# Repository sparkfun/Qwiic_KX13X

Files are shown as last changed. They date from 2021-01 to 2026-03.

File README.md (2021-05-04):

SparkFun Triple-Axis Accelerometer Breakout - KX13x (Qwiic)
========================================

<table class="table table-hover table-striped table-bordered">
    <tr align="center">
      <td></td>
      <td></td>
    </tr>
    <tr align="center">
      <td><a href="https://www.sparkfun.com/products/17871">SparkFun Triple-Axis Accelerometer Breakout - KX132 (Qwiic)</a></td>
      <td><a href="https://www.sparkfun.com/products/17589">SparkFun Triple-Axis Accelerometer Breakout - KX134 (Qwiic)</a></td>
    </tr>
</table>

The Triple-Axis Accelerometer Breakout - KX132 & KX134 (Qwiic) are simple Qwiic breakouts for a pair of high-speed digital accelerometers from Kionix. Both accelerometers have four user-selectable ranges (KX132: &plusmn;2/4/8/16g & KX134: &plusmn;8/16/32/64g) with sensitivity as high as 17367 counts/g @&plusmn;2g (highest KX134 setting is 4424 counts/g @&plusmn;8g) and Output Data Rate up to 25600Hz. The KX134 and KX132 also feature a host of accelerometer features including Freefall detection, Directional Tap<sup>&trade;</sup> and Double-Tap<sup>&trade;</sup> detection, tilt orientation detection and more.

Repository Contents
-------------------

* **/Documentation** - Data sheets, additional product information
* **/Hardware** - Eagle design files (.brd, .sch)
* **/Production** - Production panel files (.brd)

Documentation
--------------
* **[SparkFun Qwiic KX13x Library](https://github.com/sparkfun/SparkFun_KX13X_Arduino_Library)** - Arduino library for the Triple-Axis Accelerometer Breakout - KX13x (Qwiic).
* **[SparkFun Qwiic KX13x_Py](https://github.com/sparkfun/Qwiic_KX13X_Py)** - Python module for the Triple-Axis Accelerometer Breakout - KX13x (Qwiic).
* **[Hookup Guide](https://learn.sparkfun.com/tutorials/triple-axis-accelerometer-breakout---kx13x-qwiic-hookup-guide-)** - Basic hookup guide for the Triple-Axis Accelerometer Breakout - KX13x (Qwiic).

Product Versions
----------------
* [SEN-17871](https://www.sparkfun.com/products/17871) - KX132 Version initial release (v10).
* [SEN-17589](https://www.sparkfun.com/products/17589) - KX134 Version initial release (v10).

License Information
-------------------

This product is _**open source**_! 

Please review the LICENSE.md file for license information. 

If you have any questions or concerns on licensing, please contact technical support on our [SparkFun forums](https://forum.sparkfun.com/viewforum.php?f=152).

Distributed as-is; no warranty is given.

- Your friends at SparkFun.

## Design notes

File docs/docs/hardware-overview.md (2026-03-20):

# Hardware Overview

## KX132 & KX134 3-Axis Accelerometers

First up let's examine the two accelerometers on the boards, highlight their specifications and how they differ. The KX134-1211 and KX132-1211 offer the following features:

* Four User-Selectable Measurement Ranges
  * KX134: ±8 / 16 / 32 / 64g
  * KX132: ±2 / 4 / 8 / 16g
* User-configurable 3-stage Advanced Data Path (ADP) with low-pass filter, low-pass/high-pass filter and RMS calculation engine
* User-selectable Low Power or High-Performance Modes
* Configurable Output Data Rate (ODR) up to 25,600Hz
* High resolution Wake-Up / Back-to-Sleep functions with configurable thresholds (as low as 15.6mg on the KX134 & 39mg on the KX132)
* Free fall detection
* Directional-Tap™/Double-Tap™
* Device Orientation algorithms
* Embedded 512-byte FIFO buffer (continues to record while being read)
* Digital I²C up to 3.4MHz and Digital SPI up to 10MHz

<figure align="center">
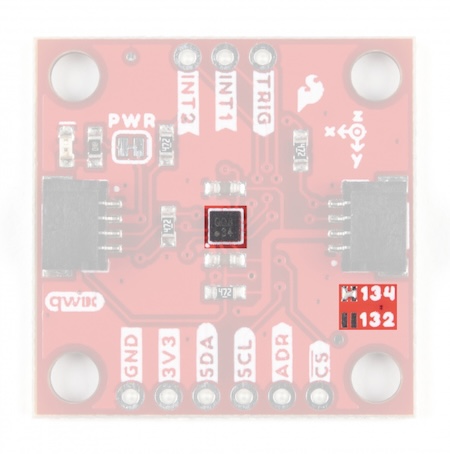
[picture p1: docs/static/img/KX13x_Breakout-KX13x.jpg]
Photo highlighting KX134 IC and KX13x version jumpers

<figcaption>KX134 IC and KX13x version jumpers</figcaption>
</figure>

:::note
As these boards both share the same PCB design, a closed solder jumper located below the "right" side Qwiic connector indicates the version (KX132 or KX134). The photo above highlights this solder jumper. This solder jumper does *not* effect the functionality of the board and is purely for identification purposes.
:::

The KX13x also includes an integrated voltage regulator to maintain consistent performance across its entire supply voltage range (**1.7** to **3.6V**). The table below outlines some of the electrical and functional characteristics of the KX134-1211 and KX132-1211 from the sensors' datasheets. All values in the table apply to both accelerometers unless specifically noted in the table or notes below it. Refer to the accelerometers' datasheets for a full overview: [KX132-1211](https://cdn.sparkfun.com/assets/d/a/1/c/0/KX132-1211-Specifications-Rev-1.0.pdf) & [KX134-1211](https://cdn.sparkfun.com/assets/6/a/2/c/b/KX134-1211-Specifications-Rev-1.0.pdf).

| Parameter | | Units | Min | Typical | Max |
| --- | --- | --- | --- | --- | --- |
| Supply Voltage (VDD) | | V | 1.7 | 2.5 (3.3 for use with Qwiic) | 3.6 |
| Current Consumption (Accelerometer Only) | High Performance w/Wake-up Detection (ODR=800Hz) | µA | | 148 | |
| | Low Power w/Wake-up Detection (ODR=0.781Hz, 2 samples averaged) | µA | | 0.53 | |
| | Standby | µA | | 0.50 | |
| Operating Temperature Range | | °C | -40 | - | 105 |
| Output Data Rate | | Hz | 0.781 | 50 | 25600 |
| Sensitivity (16 bit) | ±2g <sup>[1]</sup> | counts/g | 14501 | 16384 | 17367 |
| | ±4g <sup>[1]</sup> | counts/g | 7700 | 8192 | 8684 |
| | ±8g | counts/g | 3768 | 4096 | 4424 |
| | ±16g | counts/g | 1884 | 2048 | 2212 |
| | ±32g <sup>[2]</sup> | counts/g | 942 | 1024 | 1106 |
| | ±64g <sup>[2]</sup> | counts/g | 471 | 512 | 553 |
| Noise <sup>[3]</sup> | RMS | mg | | KX134: 1.9 / KX132: 0.7 | |
| | Density | µg/√Hz | | KX134: 300 / KX132: 150 | |
| I²C Address | | | | 0x1E (0x1F alternate) | |

> **[1]** Reminder: ±2/4g ranges are only available on the KX132.  
> **[2]** Reminder: ±32/64g ranges are only available on the KX134.  
> **[3]** Acceleration data noise varies depending on ODR, power mode & Average Filter Control settings. Noise measuring settings: High-Performance Mode (RES=1), ODR=50Hz, IIR Filter Enabled and IIR filter corner frequency set to ODR/2. Refer to Table 1 in the sensors' Datasheets as well as the Technical Reference Manuals for more information.

---

## Pinout

The KX13x Breakouts' I²C and SPI interface share the same pins so users must select the interface mode by altering the state of the ADR/SDO pin. The ADR jumper sets the state of the ADR/SDO pin (more on that in the Solder Jumpers section). Both breakouts operate in I²C mode by default. We've labeled these shared pins so I²C labels are visible from the front and SPI labels are visible when viewed from the back.

<figure alight="center">
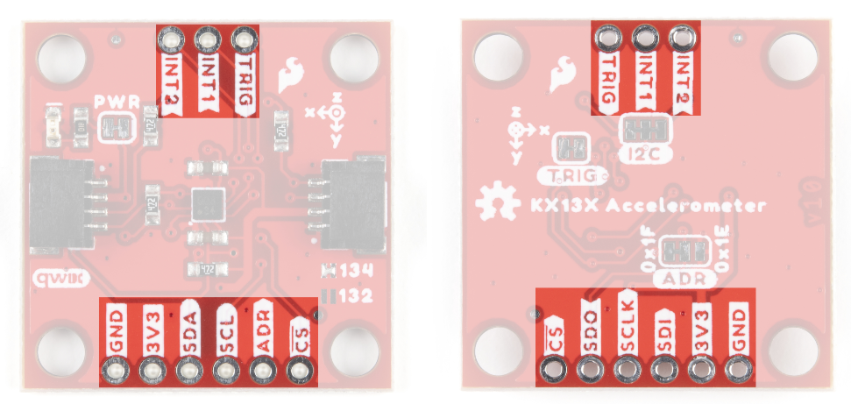
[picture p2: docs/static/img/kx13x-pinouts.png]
Photo highlighting the pinouts of the KX13x boards

<figcaption>The pinouts of the KX13x boards</figcaption>
</figure>

### Qwiic and I²C Interface

As you would expect on a Qwiic breakout, the boards break out the KX134's I²C pins to a pair of Qwiic connectors to easily integrate the board into a Qwiic system. The I²C pins are also routed to a standard 0.1" spaced header for PTH soldering.

<figure align="center">
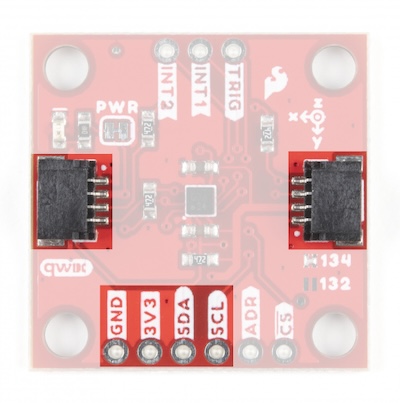
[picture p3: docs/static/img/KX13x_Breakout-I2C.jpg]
Photo highlighting the Qwiic connectors and I2C PTH pins.

<figcaption>The Qwiic connectors and I2C PTH pins.</figcaption>
</figure>

:::note
The Qwiic interface is great for general use cases on the lower acceleration ranges and for testing the higher acceleration settings but we recommended to solder the connections for long-term and high-acceleration projects to avoid communication issues.
:::

### SPI Interface

Communicating via SPI on the Qwiic KX13x is ideal for taking advantage of the maximum Output Data Rate as the Digital SPI interface on the KX13x-1211 can operate at speeds up to 10MHz.

The Qwiic KX13x breaks out the SPI interface to the same standard 0.1" spaced header as the I²C pins. As mentioned above, the board ships with the I²C interface enabled by default so to switch to the SPI interface users need to **open** the ADR jumper by severing the trace in between the "Center" and "Left" pads and connect the SDO/ADR pin to SDI/CIPO on your microcontroller.

<figure align="center">
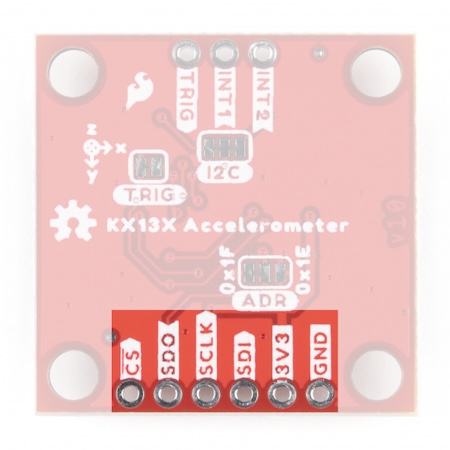
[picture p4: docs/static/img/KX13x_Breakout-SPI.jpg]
Photo highlighting the SPI PTH pins

<figcaption>SPI PTH pins</figcaption>
</figure>

### Interrupt and Trigger Pins

The KX13x has two physical interrupt pins as well as a trigger pin for FIFO buffer control. Both of the physical interrupts operate as push-pull, enter a high-impedence (high-Z) state during the Power-On-Reset (POR) procedure and are driven LOW after POR. Connect these pins to external interrupt-capable pins on your microcontroller to use the interrupt functionalities. Refer to the Interrupt and Buffer examples in the Qwiic KX13x [Arduino](https://github.com/sparkfun/SparkFun_KX13X_Arduino_Library) and [Python](https://github.com/sparkfun/Qwiic_KX13X_Py) libraries for a demonstration of using the interrupt pins.

The Trigger pin controls the FIFO buffer. By default, the Qwiic KX13x ties this pin to ground through the TRIG jumper. Users who wish to use the Trigger pin must **open** that jumper before tying it to a pin on their microcontroller. Refer to the Datasheets ([KX132](https://cdn.sparkfun.com/assets/d/a/1/c/0/KX132-1211-Specifications-Rev-1.0.pdf) & [KX134](https://cdn.sparkfun.com/assets/6/a/2/c/b/KX134-1211-Specifications-Rev-1.0.pdf)) and either Technical Reference Manuals ([KX132](https://cdn.sparkfun.com/assets/9/9/a/5/6/KX132-1211-Technical-Reference-Manual-Rev-1.0.pdf) or [KX134](https://cdn.sparkfun.com/assets/4/7/f/9/9/KX134-1211-Technical-Reference-Manual-Rev-1.0.pdf)) for more information on using this pin to control the FIFO buffer.

---

## Solder Jumpers

If you have never worked with solder jumpers and PCB traces before or would like a quick refresher, check out our [How to Work with Solder Jumpers and PCB Traces](https://learn.sparkfun.com/tutorials/how-to-work-with-jumper-pads-and-pcb-traces) tutorial for detailed instructions and tips.

The Qwiic KX13x has four jumpers labeled ADR, I2C, TRIG and PWR. In this section we'll cover each jumper's purpose, their default states and how to configure them to alter the functionality of the KX13x Breakouts.

<figure align="center">
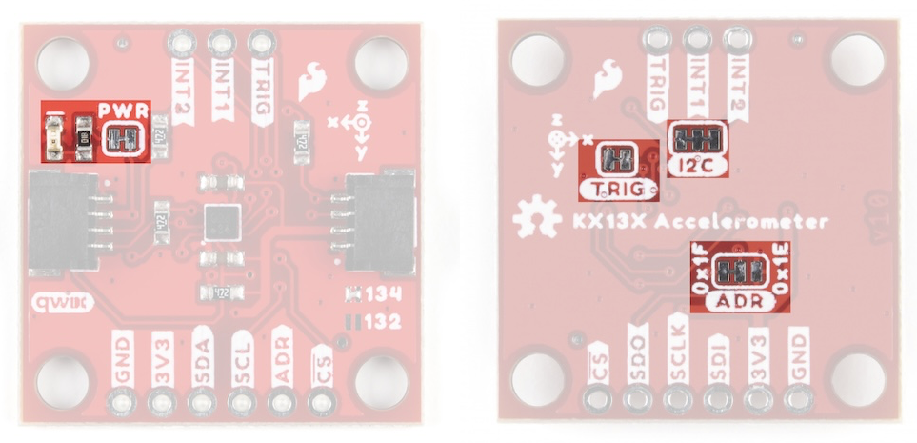
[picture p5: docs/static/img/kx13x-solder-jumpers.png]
Solder Jumpers

<figcaption>Solder Jumpers</figcaption>
</figure>

### Address (ADR) Jumper

This 3-way jumper selects the I²C address of the KX13x and also selects the communication interface for the chip by pulling the ADR/SDO pin to either **3.3V**, **0V/Ground** or **No Connect**. By default, the ADR/SDO is pulled to **3.3V** via a **4.7kΩ** resistor to set the KX134 to operate in I²C mode with the I²C address as **0x1E**.

To change the I²C address to **0x1F**, sever the trace between the "Center" and "Left" pads and then connect the "Center" and "Right" pads together to pull the ADR/SDO pin to **0V/Ground**.

Finally, to set the Qwiic KX13x to SPI mode, sever the trace between the "Center" and "Left" pads of the ADR jumper (default setting) to leave the ADR/SDO pin **Floating/No Connect**. After adjusting the jumper, connect the SDO pin to your controller's SDI/COPI pin.

### I²C Jumper

The I²C jumper on the Qwiic KX13x pulls the SDA and SCL lines to **3.3V** via a pair of **4.7kΩ** resistors. The default state of this jumper is **CLOSED**. Open the jumper by severing the traces between the three pads to disable the pullups on these lines.

If you have more than one device on a single I²C bus, best practices recommend to only maintain a single pair of pullup resistors to avoid creating too strong of a parallel resistance. A strong parallel resistance can lead to communication issues on the bus. Take note that if you are using a single set of pull-up resistors on your I²C bus, make sure all devices operate at the same [logic level](https://learn.sparkfun.com/tutorials/logic-levels) or are properly shifted to avoid damage to the device(s).

### Trigger (TRIG) Jumper

The Trigger jumper ties the TRIG pin on the KX13x-1211 to **0V/Ground**. The default state of this jumper is **CLOSED**. To use the Trigger pin for FIFO control, open the jumper and connect the TRIG PTH pin to a digital I/O pin on your microcontroller. Refer to section 2.5 in the Technical Reference Manuals ([KX132](https://cdn.sparkfun.com/assets/9/9/a/5/6/KX132-1211-Technical-Reference-Manual-Rev-1.0.pdf) or [KX134](https://cdn.sparkfun.com/assets/4/7/f/9/9/KX134-1211-Technical-Reference-Manual-Rev-1.0.pdf)) for more information on using Trigger Mode.

### Power LED (PWR) Jumper

The Power LED jumper (labeled PWR on the board) completes the power LED circuit on the board by tying the anode of the LED to **3.3V** via a **1kΩ** resistor. The jumper is **CLOSED** by default. Disable the power LED by severing the trace between the two pads. Disabling the LED helps reduce the total current draw of the board and is particularly helpful for low-power or battery-powered applications.

---

## Board Dimensions

The Triple Axis Accelerometer Breakout - KX13x (Qwiic) matches the standard 1x1" (25.4mm x 25.4mm) dimensions for Qwiic breakouts and has four mounting holes that fit a [4-40 screw](https://www.sparkfun.com/products/10453).

<figure align="center">
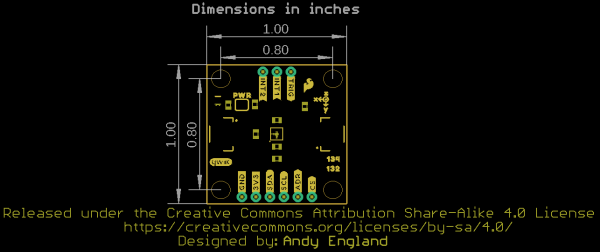
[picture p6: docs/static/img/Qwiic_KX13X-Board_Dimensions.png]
Board Dimensions

<figcaption>Board Dimensions</figcaption>
</figure>

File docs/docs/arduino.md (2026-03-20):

# Arduino Library

The SparkFun KX13x Arudino library makes it easy to get started measuring acceleration data from the sensor. Install the library through the Arduino Library Manager by searching for **"SparkFun KX13x Arduino Library"**. If you prefer manually downloading the library, you can grab it from the [GitHub repository](https://github.com/sparkfun/SparkFun_KX13X_Arduino_Library).

## Examples

The SparkFun Qwiic KX13x Arduino Library includes four examples to get started with both KX13x boards.

### Example 1 - Basic Readings

Example 1 is a basic example to demonstrate how to read data from the accelerometer. Open the example by navigating to **"File > Examples > SparkFun Qwiic KX13x Library > Example1BasicReadings"**. Next, open the **Tools** menu and select your board (in this case, Arduino Uno) and correct Port your board enumerated on. Upload the code, open the [serial monitor](https://learn.sparkfun.com/tutorials/terminal-basics) and set the baud rate to **115200**.

The example defaults to use the KX132 so if you are using the KX134, make sure to comment/uncomment the appropriate line:

```c
SparkFun_KX132 kxAccel;
//SparkFun_KX134 kxAccel; // For the KX134, uncomment this and comment line above
```

The setup initializes the sensor and performs a software reset, configures it to operate at the 16g range and enable the accelerometer. Just as above, make sure to select the appropriate option for either the KX132/134 as the code defaults to the KX132.

```c
    if( !kxAccel.begin() )
    {
        Serial.println("Could not communicate with the the KX13X. Freezing.");
        while(1);
    }

    Serial.println("Ready.");

    if( kxAccel.softwareReset() )
        Serial.println("Reset.");

    //Give some time for the accelerometer to reset.
    //It needs two, but give it five for good measure.
    delay(5);

    // Many settings for KX13X can only be
    // applied when the accelerometer is powered down.
    // However there are many that can be changed "on-the-fly"
    // check datasheet for more info, or the comments in the
    // "...regs.h" file which specify which can be changed when.
    kxAccel.enableAccel(false);

    kxAccel.setRange(SFE_KX132_RANGE16G);         // 16g Range
    //kxAccel.setRange(SFE_KX134_RANGE16G);         // 16g for the KX134

    kxAccel.enableDataEngine();     // Enables the bit that indicates data is ready.
    // kxAccel.setOutputDataRate(); // Default is 50Hz
    kxAccel.enableAccel();
}
```

After initializing the IC, the code prints out data for all three axes every 20ms. The delay here is important as it should be 1/ODR (Output Data Rate) and the default setting is 50Hz.

```c
void loop() {

  myData = kxAccel.getAccelData();
  Serial.print("X: ");
  Serial.print(myData.xData, 4);
  Serial.print("g ");
  Serial.print(" Y: ");
  Serial.print(myData.zData, 4);
  Serial.print("g ");
  Serial.print(" Z: ");
  Serial.print(myData.zData, 4);
  Serial.println("g ");

  delay(20); // Delay should be 1/ODR (Output Data Rate), default is 50Hz

}
```

### Example 2 - Interrupts

Example 2 shows how to use the hardware interrupt pin(s) on the accelerometer. In order to use this example, connect the INT1 pin on the KX13x breakout to an interrupt-capable pin. This example assumes a SparkFun RedBoard Qwiic is used so adjust the code as necessary. To follow along with this example (as well as the Buffer Example), assemble your circuit with INT1 connected to `2` on your development board.

If you aren't sure which pins on your development board are capable of external interrupts, [this reference page](https://www.arduino.cc/reference/pt/language/functions/external-interrupts/attachinterrupt/) has a list of available pins on common Arduino development boards.

Along with creating the KX13x and data objects, the code sets the physical interrupt pin as `2`.

```c
byte dataReadyPin = 2;
```

The code initializes the accelerometer and disables the accelerometer briefly to configure the interrupt settings for data ready on INT1:

```c
kxAccel.enableDataEngine();             //  Enables the bit that indicates data is ready.
kxAccel.enablePhysInterrupt();          //  Enables interrupt pin 1
kxAccel.routeHardwareInterrupt(0x10);   //  Routes the data ready bit to pin 1
```

After initializing the sensor, the main loop monitors the `dataReadyPin` (`D1`) and if it is HIGH, prints out data for all three axes:

```c
void loop() {

  if( digitalRead(dataReadyPin) == HIGH ){ // Wait for new data to be ready.

    myData = kxAccel.getAccelData();
    Serial.print("X: ");
    Serial.print(myData.xData, 4);
    Serial.print("g ");
    Serial.print(" Y: ");
    Serial.print(myData.zData, 4);
    Serial.print("g ");
    Serial.print(" Z: ");
    Serial.print(myData.zData, 4);
    Serial.println("g ");

     //kxAccel.clearInterrupt();// Because the data is being read in "burst"
     //mode, meaning that all the acceleration data is being read at once, we don't
     //need to clear the interrupt.
  }
  delay(20); // Delay should be 1/ODR (Output Data Rate), default is 50Hz
}
```

### Example 3 - Buffer

The third example shows how to configure and use the KX13x buffer settings to trigger hardware interrupts when the buffer is full. Just like Example 2, the code sets the physical interrupt/data ready pin as `2` which is driven HIGH when the buffer is full. Just like with Example 2, in order to use this example, connect the INT1 pin on the KX13x breakout to an interrupt-capable pin. This example assumes a SparkFun RedBoard Qwiic/Arduino Uno is used so adjust the code as necessary.

```c
byte dataReadyPin = 2;
```

The setup configures the KX13x to enable the buffer interrupt as a hardware interrupt in FIFO mode:

```c
kxAccel.enableBufferInt();              //  Enables the Buffer interrupt
kxAccel.enablePhysInterrupt();          //  Enables interrupt pin 1
kxAccel.routeHardwareInterrupt(0x40);   //  Routes the data ready bit to pin 1

kxAccel.enableSampleBuffer();           // Enable buffer.
kxAccel.setBufferOperationMode(0x00);   // Enable the buffer to be FIFO.
```

After setting everything up, the main loop waits for the buffer to fill and drive the data ready pin HIGH. Once the pin goes HIGH, the code prints out acceleration data for all three axes just like the other examples.

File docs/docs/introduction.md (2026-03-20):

---
slug: /
---
# Introduction

The SparkFun [Triple Axis Accelerometer Breakout - KX134 (Qwiic)](https://www.sparkfun.com/products/17589) and [Triple Axis Accelerometer Breakout - KX132 (Qwiic)](https://www.sparkfun.com/products/17871) offer two high-speed additions to SparkFun's accelerometer selection featuring the KX134-1211 and KX132-1211 3-axis digital accelerometers from Kionix. The KX134 and KX132 both include a host of accelerometer features including Freefall detection, Directional Tap™ and Double-Tap™ detection, tilt orientation detection and more. The breakouts can interface with controllers using both I²C and SPI at high speeds so you can use it in either an existing Qwiic/I²C chain or SPI bus.

The KX134 is a low-power, 16-bit resolution 3-axis accelerometer capable of measuring ±8g/16g/32g/64g (user selectable) and has up to a 10kHz (max) output data rate making it ideal for high-g measurements as well as high-speed applications such as vibration sensing. The KX132 offers nearly the same data specifications at smaller acceleration (±2g/4g/8g/16g) ranges. At lower ranges the sensitivity can be set as high as 17367 counts/g (@±2g), so it's a great for applications looking for both high-speed data rates and high-sensitivity measurements at lower acceleration ranges.

**Note:** Any reference in this guide specific to either version of these breakouts will denote the version (KX132 or KX134) discussed. We'll use the terms "KX13x Breakout(s)" or "KX13x" when discussing subjects or specifications pertaining to both boards or both accelerometers.

## Required Materials

In order to follow along with this tutorial you'll need a few items along with your KX13x Breakout.

* A microcontroller or single-board computer (SBC) like a Raspberry Pi to communicate with the board.
* At least one Qwiic cable is recommended to connect your KX13x Breakout to your microcontroller/SBC:

For users who wish to communicate with the KX13x Breakout using SPI, some through-hole soldering will be necessary. You may already have a few of these items but if not the tools and products below will help with that assembly:

## Suggested Reading

If you aren't familiar with the Qwiic system, we recommend reading [here for an overview](https://www.sparkfun.com/qwiic):

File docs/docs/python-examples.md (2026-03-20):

# Python Examples

The Qwiic KX13X Python Package examples  to get users started with either Qwiic KX13x board using Python. The examples are detailed on [this page on GitHub](https://github.com/sparkfun/qwiic_kx13x_py/blob/main/examples/README.md).

In this section we'll go over the basic use of the sensor with Python. For more detailed documentation on using the Qwiic KX13x Python package, visit the [Qwiic KX13x Python Package Documentation](http://docs.sparkfun.com/qwiic_kx13x_py/) site.

Note, the examples default to using the Qwiic KX132 so if a Qwiic KX134 is used, adjust the code by un-commenting this line:

```python
myKX = qwiic_kx13x.QwiicKX134()
```

And replace any instance of `kx132` with `kx134`. The acceleration range can also be adjusted by uncommenting this line and adjusting the value set for the range:

```python
myKx.set_range(myKx.KX132_RANGE8G)
```

## Simple Example

This example is a basic example demonstrating how to initialize a Qwiic KX13x board on the I²C bus using its default settings. The full example code can be found below if you would prefer to copy it into your preferred Python interpreter:

```python
import qwiic_kx13x
import time
import sys

def runExample():

    print("\nSparkFun KX13X Accelerometer Example 1\n")
    # myKx = qwiic_kx13x.QwiicKX134() # If using the KX134 un-comment this line and replace other instances of "kx132" with "kx134"
    myKx = qwiic_kx13x.QwiicKX132()

    if myKx.connected == False:
            print("The Qwiic KX13X Accelerometer device isn't connected to the system. Please check your connection", \
                    file=sys.stderr)
            return

    if myKx.begin():
        print("Ready.")
    else:
        print("Make sure you're using the KX132 and not the KX134")

    if (myKx.software_reset()):
        print("Reset")

    # Many settings for KX13X can only be
    # applied when the accelerometer is powered down.
    # However there are many that can be changed "on-the-fly"
    # check datasheet for more info
    myKx.enable_accel(False)
    # myKx.set_range(myKx.KX134_RANGE16G)  # If using the KX134 un-comment this line and comment out below line
    myKx.set_range(myKx.KX132_RANGE16G)
    myKx.enable_data_engine()
    myKx.enable_accel()

    while True:
        if myKx.data_ready():    
            myKx.get_accel_data()
            # If using the KX134 un-comment the print below and comment out the print below that
            # print("X: {0}g Y: {1}g Z: {2}g".format(myKx.kx134_accel.x,
            #                         myKx.kx134_accel.y,
            #                         myKx.kx134_accel.z))
            print("X: {0} Y: {1} Z: {2}".format(myKx.kx132_accel.x,
                                                myKx.kx132_accel.y,
                                                myKx.kx132_accel.z))
            time.sleep(.02) #Set delay to 1/Output Data Rate which is by default 50Hz 1/50 = .02

if __name__ == '__main__':
 try:
  runExample()
 except (KeyboardInterrupt, SystemExit) as exErr:
  print("\nEnding Example 1")
  sys.exit(0)
```

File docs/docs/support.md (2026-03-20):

# Support

## Switching to SPI

As we've covered before in this tutorial, using either KX13x Breakout in SPI mode requires a slight modification to the board. The ADR Jumper must be **completely opened** so the ADR/SDO pin is floating prior to being connected to the SPI controller's SDI/COPI pin. Also, make sure the controller the KX13x Breakout connects to runs at **3.3V** logic to avoid damaging the IC. Using either accelerometer breakout with a **5V** controller requires [level shifting](https://www.sparkfun.com/categories/361) the signal.

## Support

If you need technical assistance and more information on a product that is not working as you expected, visit the [SparkFun Community](https://community.sparkfun.com). The community forums are monitored by the SparkFun Technical Support Team and the SparkFun community as a whole.

### Existing Issue

Spot something wrong? Please check the list of reported and fixed issues [on GitHub](https://github.com/sparkfun/Qwiic_KX13X/issues).

### Discrepancies in the Documentation

All of this documentation can be modified by you! Please help us make it better.

* The documentation files for these pages are contained in the [`docs` folder of the Qwiic_KX13X repository](https://github.com/sparkfun/Qwiic_KX13X/tree/main/docs).

#### Spot something wrong?

If a section of the documentation is incorrect, please [open an issue](https://github.com/sparkfun/Qwiic_KX13X/issues) and let us know.

#### Do you have a suggested correction?

1. With a GitHub account, fork this repo
2. Add your correction(s) or improvement(s) to the markdown file(s)
3. File a pull request with your changes, and enjoy making the ~~words~~ ~~worlds~~ world a better place.
    * Once received, the documentation specialist will automatically be notified.
    * We will review your suggested improvement(s) to make sure they are correct and fit within our documentation standards.

### Problems in the Hardware Design

All of our designs are open-source! Please help us make it better.

* Our board design files are contained in the [`Hardware` folder of the Qwiic KX13X repository](https://github.com/sparkfun/Qwiic_KX13X/tree/main/Hardware).

#### Does something not make sense?

If part of the design is confusing, please [open an issue](https://github.com/sparkfun/Qwiic_KX13X/issues) and let us know.

#### Did we forget to include an important function of the board?

Please keep in mind that we may intentionally exclude certain functions of the board to meet our product design requirements.

If part of the board's functionality is missing, please [open an issue](https://github.com/sparkfun/Qwiic_KX13X/issues) and file a feature request.

#### Do you wish to contribute directly to improving the board design?

1. With a GitHub account, Fork this repo
2. Add your design improvement(s)
3. File a pull request with your changes, and enjoy making the ~~words~~ ~~worlds~~ world a better place.
    * Once received, the engineer in charge of the original design will automatically be notified.
    * We will review your suggested improvement(s), if they are within our board design standards and meet our product design requirements, we will flag these changes for our next board revision. *(Please note, that even if your suggestion is accepted, these changes may not be immediate. We may have to cycle through our current product inventory first.)*

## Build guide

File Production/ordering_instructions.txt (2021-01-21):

panel size, 195x143mm
PCB thickness, 1.6mm
number of layers, 2
soldermask color, Red
silkscreen color, White
oz copper, 1oz
finish, HASL lead free
stencils, top
pcs per panel, 35
min trace width, 0.1778mm / 0.0070in
min drill size, 0.3810mm / 0.0150in

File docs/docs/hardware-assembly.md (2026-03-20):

# Hardware Assembly  

Now that we're familiar with the KX13x and the other hardware present on the KX13x Breakouts we can start assembling our circuit. Depending on your preferred use of the accelerometer, you'll want to connect either using I²C using the Qwiic connector (or the PTH header) or via SPI using the PTH header on the board.

## Qwiic/I²C Assembly

The fastest and easiest way to get started using the breakout is using either of the Qwiic connectors, a Qwiic cable and a Qwiic-enabled development board like the SparkFun RedBoard Qwiic.

If you are using a Raspberry Pi instead for our Python Package, you'll need a Pi, Qwiic cable and an adapter like the Qwiic Shim or another of our Qwiic-enabled pHATs.

<figure align="center">
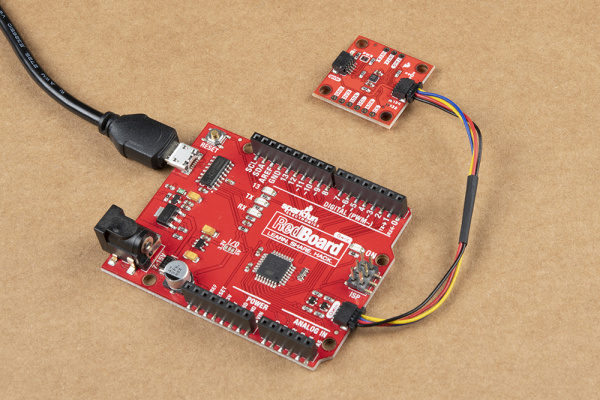
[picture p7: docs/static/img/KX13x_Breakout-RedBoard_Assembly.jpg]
Photo showing assembled Qwiic KX13x circuit with RedBoard Qwiic

<figcaption>Qwiic KX13x circuit with RedBoard Qwiic</figcaption>
</figure>

If you would prefer a more secure and permanent connection, you can solder headers or wire to the PTH header on the board. This method is recommended for permanent installations as well as high-g and vibration sensing applications.

## SPI Assembly

If you'd prefer to take advantage of the max output data rate of the KX13x, you'll want to use the SPI interface instead of the I²C interface. Assembling the KX13x Breakout in SPI mode requires some through-hole soldering. If you are not familiar with through-hole soldering, take a read through [this tutorial](https://learn.sparkfun.com/tutorials/how-to-solder-through-hole-soldering/all).

Along with tools for soldering, you'll need either some hookup wire or headers and jumper wires. Also, the Address (ADR) Jumper must be opened by severing the trace between the "Center" and "Left" pads to switch to SPI mode. After opening this jumper, connect the SDO pin to your controller's SDI/CIPO pin.

<figure align="center">
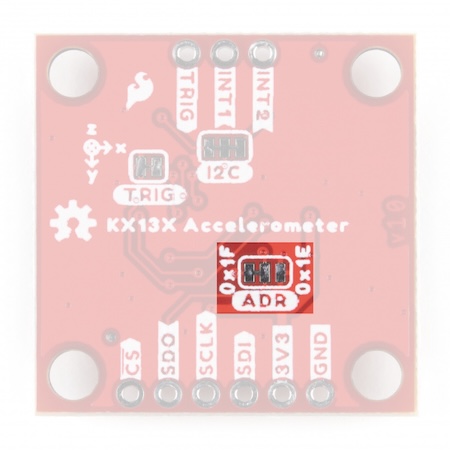
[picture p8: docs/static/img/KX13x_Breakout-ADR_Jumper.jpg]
Photo highlighting the ADR jumper on the KX13x Breakout

<figcaption>ADR Jumper</figcaption>
</figure>

With the KX13x Breakout set to SPI mode, solder headers or wire to the PTH header on the board and make the SPI connections with your controller. Remember the KX13x operates at **3.3V** logic so make sure to connect to a board running at the same [logic level](https://learn.sparkfun.com/tutorials/logic-levels) or use a [level shifter](https://www.sparkfun.com/categories/361) to adjust it to a safe voltage.

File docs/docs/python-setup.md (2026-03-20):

# Python Setup

> **Note:** This package and the included examples assume you are using the latest version of Python 3. If this is your first time using Python or I²C hardware on a Raspberry Pi, these tutorials can help you get started:
>
> - [Python Programming with the Raspberry Pi](https://learn.sparkfun.com/tutorials/python-programming-tutorial-getting-started-with-the-raspberry-pi)
> - [Raspberry Pi SPI and I2C Tutorial](https://learn.sparkfun.com/tutorials/raspberry-pi-spi-and-i2c-tutorial)

We've written a Python package to control the KX13x Breakouts for users who prefer a Raspberry Pi or other Python-specific development environment. You can install the `sparkfun-qwiic-kx13x` Python package hosted by PyPi through a command interface. If you prefer to manually download and build the libraries from the [GitHub repository](https://github.com/sparkfun/Qwiic_KX13X_Py).

*\*Please be aware of any package dependencies. You can also check out the repository documentation page, hosted on [Read the Docs](https://qwiic-kx13x-py.readthedocs.io/en/latest/?).*

## Installation

The first step to using this package is installing it on your system. The install method depends on the python platform. The following sections outline installation on Python, MicroPython and CircuitPython.

### Python

#### PyPi Installation

The package is primarily installed using the `pip3` command, downloading the package from the Python Index - "PyPi".

Note - the below instructions outline installation on a Linux-based (Raspberry Pi) system.

First, setup a virtual environment from a specific directory using venv:

```sh
python3 -m venv path/to/venv
```

You can pass any path as path/to/venv, just make sure you use the same one for all future steps. Visit this link for more [information on venv](https://docs.python.org/3/library/venv.html).

Next, install the qwiic package with:

```sh
path/to/venv/bin/pip3 install sparkfun-qwiic-kx13x
```

Now you should be able to run any example or custom python scripts that have `import qwiic_kx13x` by running e.g.:

```sh
path/to/venv/bin/python3 example_script.py
```

### MicroPython Installation

If not already installed, follow the [instructions here](https://docs.micropython.org/en/latest/reference/mpremote.html) to install mpremote on your computer.

Connect a device with MicroPython installed to your computer and then install the package directly to your device with mpremote mip.

```sh
mpremote mip install github:sparkfun/qwiic_kx13x_py
```

If you would also like to install the examples for this repository, issue the following mip command as well:

```sh
mpremote mip install --target "" github:sparkfun/qwiic_kx13x_py@examples
```

### CircuitPython Installation

If not already installed, follow the [instructions here](https://docs.circuitpython.org/projects/circup/en/latest/#installation) to install CircUp on your computer.

Ensure that you have the latest version of the SparkFun Qwiic CircuitPython bundle.

```sh
circup bundle-add sparkfun/Qwiic_Py
```

Finally, connect a device with CircuitPython installed to your computer and then install the package directly to your device with circup.

```sh
circup install --py qwiic_kx13x
```

If you would like to install any of the examples from this repository, issue the corresponding circup command from below. (NOTE: The below syntax assumes you are using CircUp on Windows. Linux and Mac will have different path seperators. See the [CircUp "example" command documentation](https://learn.adafruit.com/keep-your-circuitpython-libraries-on-devices-up-to-date-with-circup/example-command) for more information)

```sh
circup example qwiic_kx13x\qwiic_kx13x_ex1
circup example qwiic_kx13x\qwiic_kx13x_ex3
circup example qwiic_kx13x\qwiic_kx13x_ex4
```

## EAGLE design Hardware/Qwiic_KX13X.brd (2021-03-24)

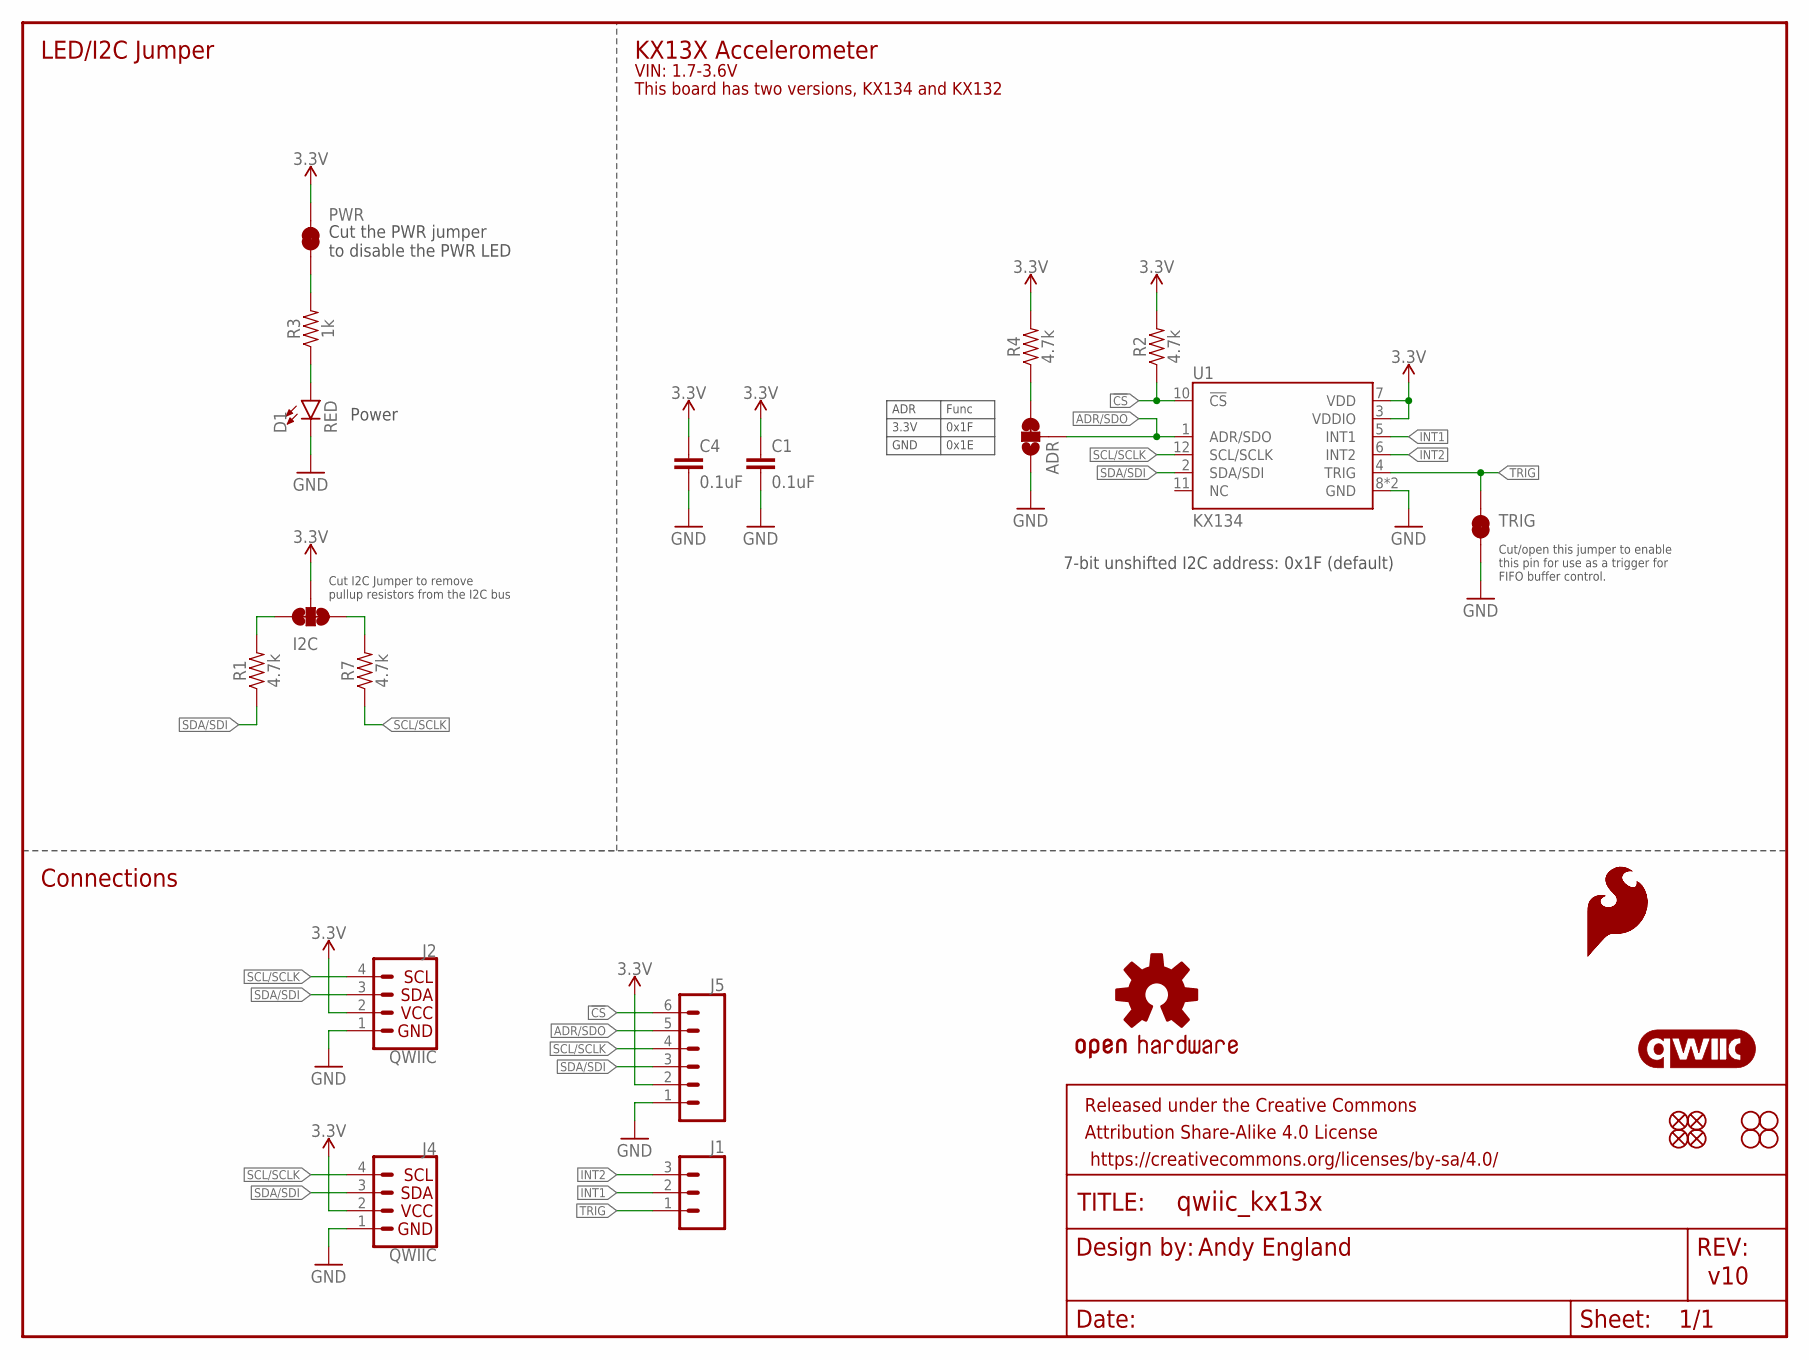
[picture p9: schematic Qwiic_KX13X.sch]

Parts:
ADR: JUMPER-SMT_3_1-NC_TRACE_SILK; SMT-JUMPER_3_1-NC_TRACE_SILK
C1, C4: 0.1uF; 0603
D1: RED; LED-0603
FRAME1: FRAME-LETTER; CREATIVE_COMMONS
I2C: JUMPER-SMT_3_2-NC_TRACE_SILK; SMT-JUMPER_3_2-NC_TRACE_SILK
J1: CONN_031X03_NO_SILK; 1X03_NO_SILK
J2, J4: QWIIC; JST04_1MM_RA
J5: CONN_06NO_SILK_NO_POP; 1X06_NO_SILK
JP1, JP2, JP5, JP6: FIDUCIALUFIDUCIAL; MICRO-FIDUCIAL
JP3, JP4, JP7, JP8: STAND-OFF
LOGO1, LOGO2: SFE_LOGO_FLAME.1_INCH; SFE_LOGO_FLAME_.1
LOGO3: QWIIC_LOGO_4MM; QWIIC_4MM
LOGO5: OSHW-LOGOS; OSHW-LOGO-S
PWR: JUMPER-SMT_2_NC_TRACE_SILK; SMT-JUMPER_2_NC_TRACE_SILK
R1, R2, R4, R7: 4.7k; 0603
R3: 1k; 0603
TRIG: JUMPER-SMT_2_NC_TRACE_SILK; SMT-JUMPER_2_NC_TRACE_SILK
U1: KX134; KX13X

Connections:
3.3V: C1.1, C4.1, I2C.2, J2.2, J4.2, J5.2, PWR.2, R2.2, R4.2, U1.3 (VDDIO), U1.7 (VDD)
!CS: J5.6, R2.1, U1.10 (!CS)
ADR/SDO: ADR.2, J5.5, U1.1 (ADR/SDO)
GND: ADR.1, C1.2, C4.2, D1.C, J2.1, J4.1, J5.1, TRIG.2, U1.8 (GND), U1.9 (GND)
INT1: J1.2, U1.5 (INT1)
INT2: J1.3, U1.6 (INT2)
unnamed: PWR.1, R3.2
unnamed: I2C.3, R1.2
unnamed: D1.A, R3.1
unnamed: I2C.1, R7.2
unnamed: ADR.3, R4.1
SCL/SCLK: J2.4, J4.4, J5.4, R7.1, U1.12 (SCL/SCLK)
SDA/SDI: J2.3, J4.3, J5.3, R1.1, U1.2 (SDA/SDI)
TRIG: J1.1, TRIG.1, U1.4 (TRIG)

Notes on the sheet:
v10
7-bit unshifted I2C address: 0x1F (default)
Power
Cut the PWR jumper to disable the PWR LED
Andy England
Cut I2C Jumper to remove pullup resistors from the I2C bus
Cut/open this jumper to enable this pin for use as a trigger for FIFO buffer control.
ADR
Func
3.3V
0x1F
0x1E
GND
KX13X Accelerometer
VIN: 1.7-3.6V
LED/I2C Jumper
Connections
This board has two versions, KX134 and KX132

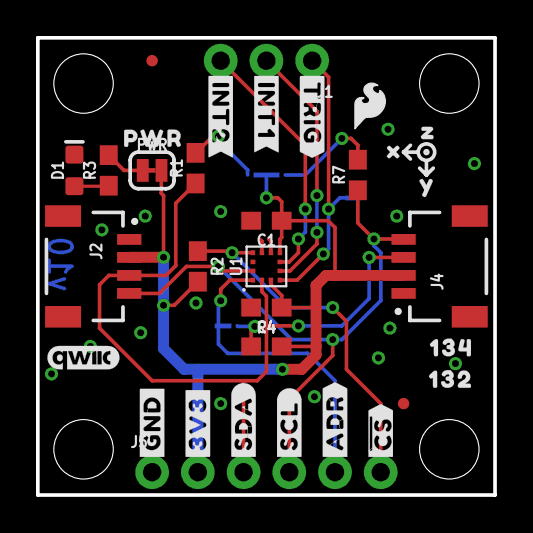
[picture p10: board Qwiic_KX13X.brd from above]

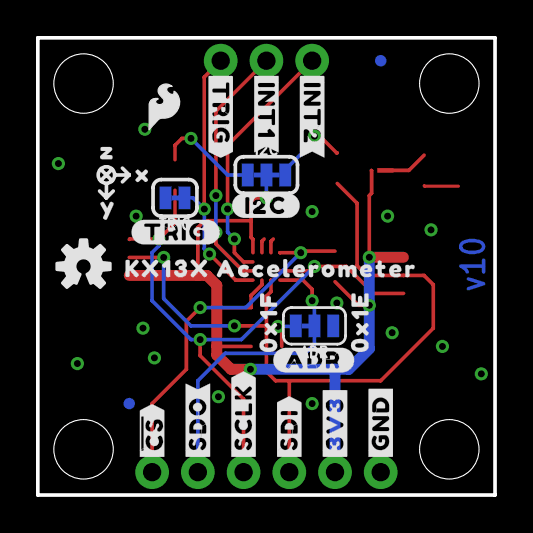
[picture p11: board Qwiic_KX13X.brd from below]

Board: 2 copper layers, 25.4 x 25.4 mm, 63 parts (25 on the bottom side), 14 nets.

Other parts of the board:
U$1, U$28: X0
U$2: #SCL#0
U$3: #SDA#0
U$4, U$5: #3V3#0
U$6, U$7: #GND#0
U$8, U$9: ##CS##0
U$10: #ADR#0
U$11, U$15: #TRIG#0
U$12, U$13: #INT1#0
U$14: 0X1E0
U$17: #TRIG#2
U$18, U$19: #INT2#0
U$20: #ADR#3
U$21, U$29: Y0
U$22: #I2C#0
U$23: 0X1F0
U$24: #SDI#0
U$25: #SCLK#0
U$26: #SDO#0
U$27: KX13X_ACCELEROMETER14
U$30, U$32: Z0
U$31: PWR0
U$33: 1320
U$34: 1340

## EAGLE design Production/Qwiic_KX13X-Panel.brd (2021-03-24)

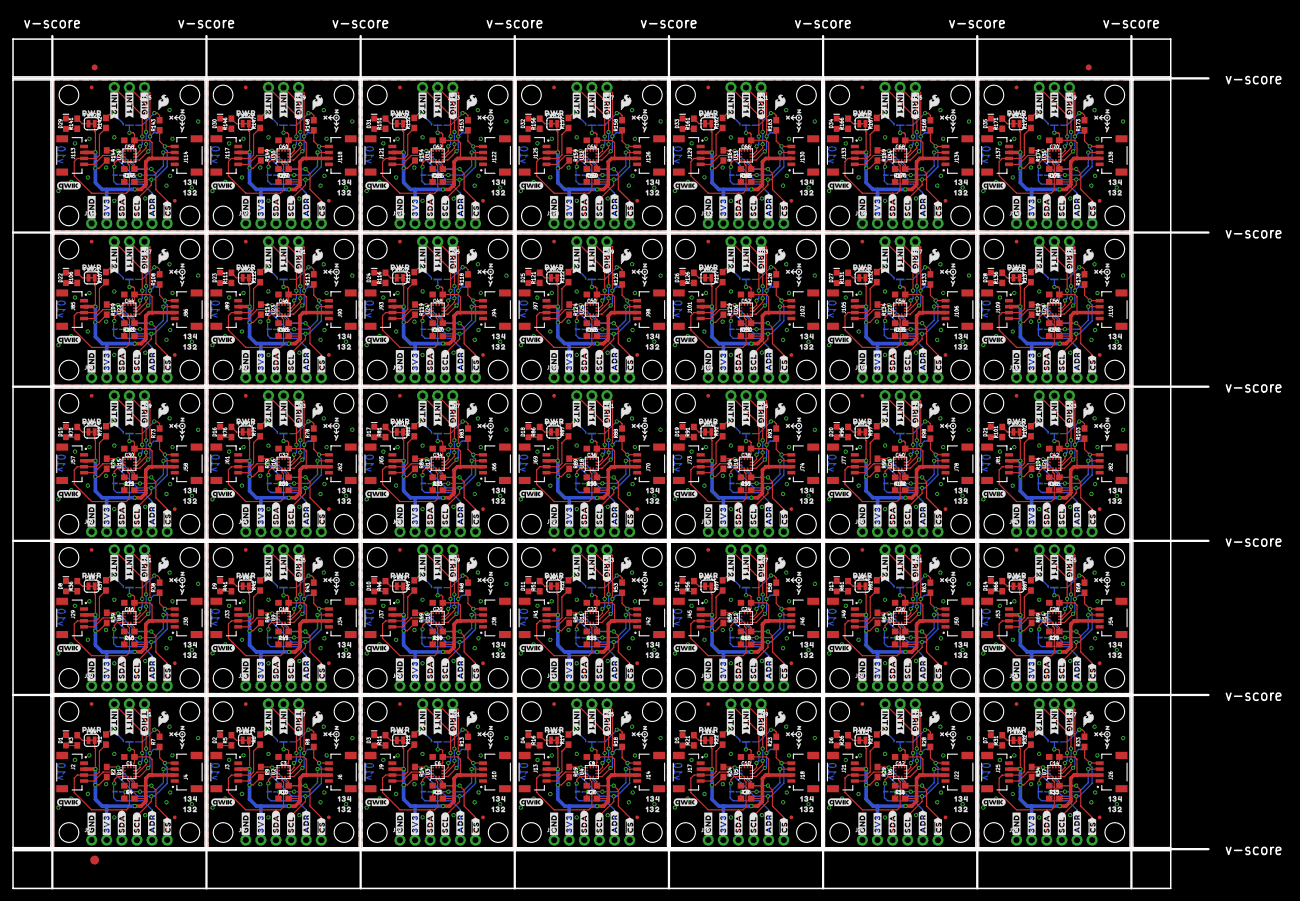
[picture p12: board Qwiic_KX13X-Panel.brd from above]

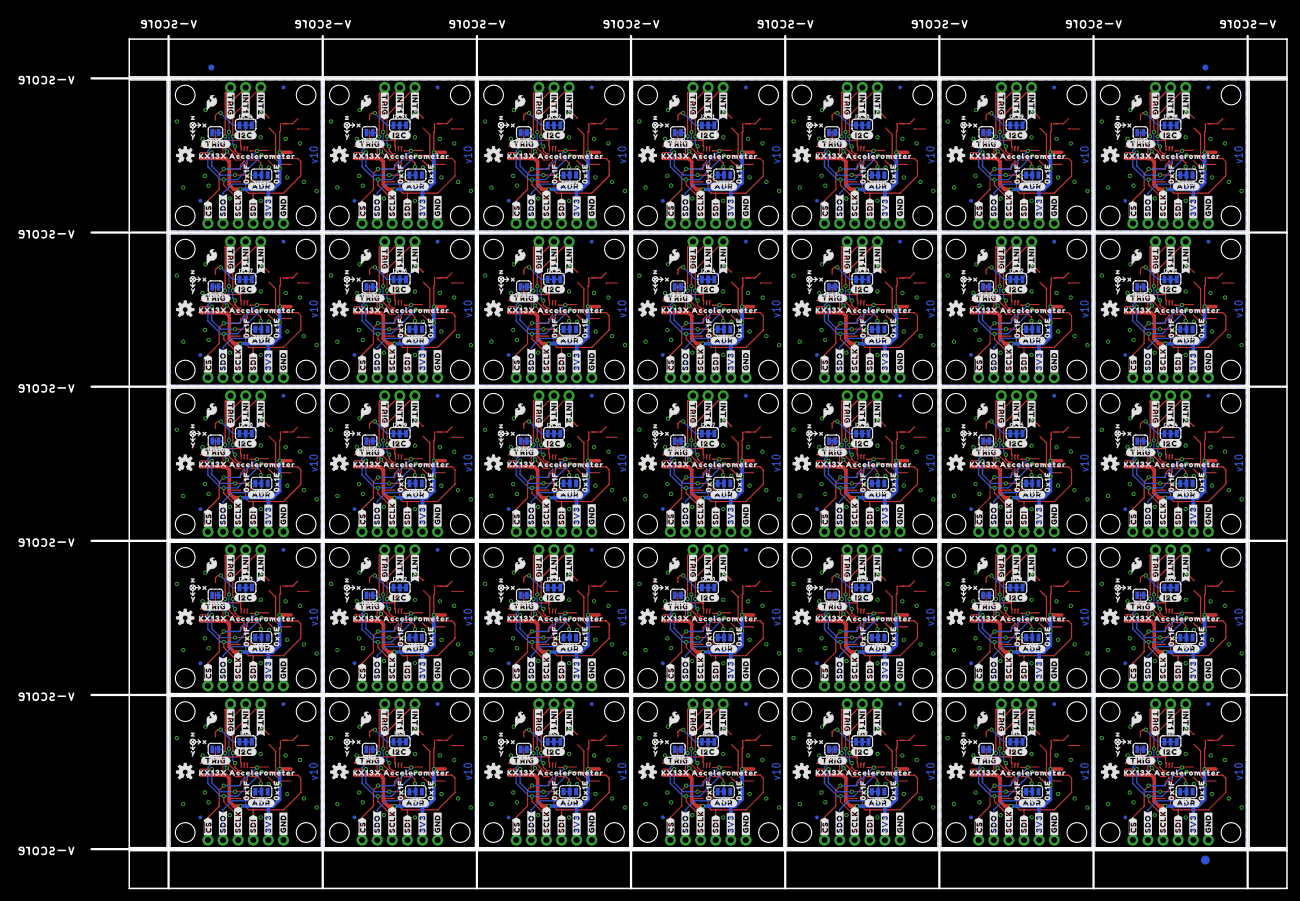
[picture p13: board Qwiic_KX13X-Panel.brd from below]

Board: 2 copper layers, 200.9 x 143.3 mm, 2176 parts (878 on the bottom side), 490 nets.

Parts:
ADR, ADR1, ADR2, ADR3, ADR4, ADR5, ADR6, ADR7, ADR8, ADR9, ADR10, ADR11, ADR12, ADR13, ADR14, ADR15, ADR16, ADR17, ADR18, ADR19, ADR20, ADR21, ADR22, ADR23, ADR24, ADR25, ADR26, ADR27, ADR28, ADR29, ADR30, ADR31, ADR32, ADR33, ADR34: JUMPER-SMT_3_1-NC_TRACE_SILK; SMT-JUMPER_3_1-NC_TRACE_SILK
C1, C2, C3, C4, C5, C6, C7, C8, C9, C10, C11, C12, C13, C14, C15, C16, C17, C18, C19, C20, C21, C22, C23, C24, C25, C26, C27, C28, C29, C30, C31, C32, C33, C34, C35, C36, C37, C38, C39, C40, C41, C42, C43, C44, C45, C46, C47, C48, C49, C50, C51, C52, C53, C54, C55, C56, C57, C58, C59, C60, C61, C62, C63, C64, C65, C66, C67, C68, C69, C70: 0.1uF; 0603
D1, D2, D3, D4, D5, D6, D7, D8, D9, D10, D11, D12, D13, D14, D15, D16, D17, D18, D19, D20, D21, D22, D23, D24, D25, D26, D27, D28, D29, D30, D31, D32, D33, D34, D35: RED; LED-0603
E$1, E$2, E$3, E$4: FIDUCIAL-1X2
E$5, E$6: FIDUCIAL-1.5X3
I2C, I2C1, I2C2, I2C3, I2C4, I2C5, I2C6, I2C7, I2C8, I2C9, I2C10, I2C11, I2C12, I2C13, I2C14, I2C15, I2C16, I2C17, I2C18, I2C19, I2C20, I2C21, I2C22, I2C23, I2C24, I2C25, I2C26, I2C27, I2C28, I2C29, I2C30, I2C31, I2C32, I2C33, I2C34: JUMPER-SMT_3_2-NC_TRACE_SILK; SMT-JUMPER_3_2-NC_TRACE_SILK
J1, J7, J11, J15, J19, J23, J27, J31, J35, J39, J43, J47, J51, J55, J59, J63, J67, J71, J75, J79, J83, J87, J91, J95, J99, J103, J107, J111, J115, J119, J123, J127, J131, J135, J139: 1X03_NO_SILK
J2, J3, J4, J6, J9, J10, J13, J14, J17, J18, J21, J22, J25, J26, J29, J30, J33, J34, J37, J38, J41, J42, J45, J46, J49, J50, J53, J54, J57, J58, J61, J62, J65, J66, J69, J70, J73, J74, J77, J78, J81, J82, J85, J86, J89, J90, J93, J94, J97, J98, J101, J102, J105, J106, J109, J110, J113, J114, J117, J118, J121, J122, J125, J126, J129, J130, J133, J134, J137, J138: QWIIC; JST04_1MM_RA
J5, J8, J12, J16, J20, J24, J28, J32, J36, J40, J44, J48, J52, J56, J60, J64, J68, J72, J76, J80, J84, J88, J92, J96, J100, J104, J108, J112, J116, J120, J124, J128, J132, J136, J140: 1X06_NO_SILK
JP1, JP2, JP5, JP6, JP11, JP12, JP13, JP14, JP19, JP20, JP21, JP22, JP27, JP28, JP29, JP30, JP35, JP36, JP37, JP38, JP43, JP44, JP45, JP46, JP51, JP52, JP53, JP54, JP59, JP60, JP61, JP62, JP67, JP68, JP69, JP70, JP75, JP76, JP77, JP78, JP83, JP84, JP85, JP86, JP91, JP92, JP93, JP94, JP99, JP100, JP101, JP102, JP107, JP108, JP109, JP110, JP115, JP116, JP117, JP118, JP123, JP124, JP125, JP126, JP131, JP132, JP133, JP134, JP139, JP140, JP141, JP142, JP147, JP148, JP149, JP150, JP155, JP156, JP157, JP158, JP163, JP164, JP165, JP166, JP171, JP172, JP173, JP174, JP179, JP180, JP181, JP182, JP187, JP188, JP189, JP190, JP195, JP196, JP197, JP198, JP203, JP204, JP205, JP206, JP211, JP212, JP213, JP214, JP219, JP220, JP221, JP222, JP227, JP228, JP229, JP230, JP235, JP236, JP237, JP238, JP243, JP244, JP245, JP246, JP251, JP252, JP253, JP254, JP259, JP260, JP261, JP262, JP267, JP268, JP269, JP270, JP275, JP276, JP277, JP278: FIDUCIALUFIDUCIAL; MICRO-FIDUCIAL
JP3, JP4, JP7, JP8, JP9, JP10, JP15, JP16, JP17, JP18, JP23, JP24, JP25, JP26, JP31, JP32, JP33, JP34, JP39, JP40, JP41, JP42, JP47, JP48, JP49, JP50, JP55, JP56, JP57, JP58, JP63, JP64, JP65, JP66, JP71, JP72, JP73, JP74, JP79, JP80, JP81, JP82, JP87, JP88, JP89, JP90, JP95, JP96, JP97, JP98, JP103, JP104, JP105, JP106, JP111, JP112, JP113, JP114, JP119, JP120, JP121, JP122, JP127, JP128, JP129, JP130, JP135, JP136, JP137, JP138, JP143, JP144, JP145, JP146, JP151, JP152, JP153, JP154, JP159, JP160, JP161, JP162, JP167, JP168, JP169, JP170, JP175, JP176, JP177, JP178, JP183, JP184, JP185, JP186, JP191, JP192, JP193, JP194, JP199, JP200, JP201, JP202, JP207, JP208, JP209, JP210, JP215, JP216, JP217, JP218, JP223, JP224, JP225, JP226, JP231, JP232, JP233, JP234, JP239, JP240, JP241, JP242, JP247, JP248, JP249, JP250, JP255, JP256, JP257, JP258, JP263, JP264, JP265, JP266, JP271, JP272, JP273, JP274, JP279, JP280: STAND-OFF
LOGO1, LOGO2, LOGO6, LOGO7, LOGO10, LOGO11, LOGO14, LOGO15, LOGO18, LOGO19, LOGO22, LOGO23, LOGO26, LOGO27, LOGO30, LOGO31, LOGO34, LOGO35, LOGO38, LOGO39, LOGO42, LOGO43, LOGO46, LOGO47, LOGO50, LOGO51, LOGO54, LOGO55, LOGO58, LOGO59, LOGO62, LOGO63, LOGO66, LOGO67, LOGO70, LOGO71, LOGO74, LOGO75, LOGO78, LOGO79, LOGO82, LOGO83, LOGO86, LOGO87, LOGO90, LOGO91, LOGO94, LOGO95, LOGO98, LOGO99, LOGO102, LOGO103, LOGO106, LOGO107, LOGO110, LOGO111, LOGO114, LOGO115, LOGO118, LOGO119, LOGO122, LOGO123, LOGO126, LOGO127, LOGO130, LOGO131, LOGO134, LOGO135, LOGO138, LOGO139: SFE_LOGO_FLAME.1_INCH; SFE_LOGO_FLAME_.1
LOGO3, LOGO8, LOGO12, LOGO16, LOGO20, LOGO24, LOGO28, LOGO32, LOGO36, LOGO40, LOGO44, LOGO48, LOGO52, LOGO56, LOGO60, LOGO64, LOGO68, LOGO72, LOGO76, LOGO80, LOGO84, LOGO88, LOGO92, LOGO96, LOGO100, LOGO104, LOGO108, LOGO112, LOGO116, LOGO120, LOGO124, LOGO128, LOGO132, LOGO136, LOGO140: QWIIC_LOGO_4MM; QWIIC_4MM
LOGO4, LOGO5, LOGO9, LOGO13, LOGO17, LOGO21, LOGO25, LOGO29, LOGO33, LOGO37, LOGO41, LOGO45, LOGO49, LOGO53, LOGO57, LOGO61, LOGO65, LOGO69, LOGO73, LOGO77, LOGO81, LOGO85, LOGO89, LOGO93, LOGO97, LOGO101, LOGO105, LOGO109, LOGO113, LOGO117, LOGO121, LOGO125, LOGO129, LOGO133, LOGO137: OSHW-LOGOS; OSHW-LOGO-S
PWR, PWR1, PWR2, PWR3, PWR4, PWR5, PWR6, PWR7, PWR8, PWR9, PWR10, PWR11, PWR12, PWR13, PWR14, PWR15, PWR16, PWR17, PWR18, PWR19, PWR20, PWR21, PWR22, PWR23, PWR24, PWR25, PWR26, PWR27, PWR28, PWR29, PWR30, PWR31, PWR32, PWR33, PWR34: JUMPER-SMT_2_NC_TRACE_SILK; SMT-JUMPER_2_NC_TRACE_SILK
R1, R2, R4, R6, R7, R8, R9, R10, R12, R13, R14, R15, R17, R18, R19, R20, R22, R23, R24, R25, R27, R28, R29, R30, R32, R33, R34, R35, R37, R38, R39, R40, R42, R43, R44, R45, R47, R48, R49, R50, R52, R53, R54, R55, R57, R58, R59, R60, R62, R63, R64, R65, R67, R68, R69, R70, R72, R73, R74, R75, R77, R78, R79, R80, R82, R83, R84, R85, R87, R88, R89, R90, R92, R93, R94, R95, R97, R98, R99, R100, R102, R103, R104, R105, R107, R108, R109, R110, R112, R113, R114, R115, R117, R118, R119, R120, R122, R123, R124, R125, R127, R128, R129, R130, R132, R133, R134, R135, R137, R138, R139, R140, R142, R143, R144, R145, R147, R148, R149, R150, R152, R153, R154, R155, R157, R158, R159, R160, R162, R163, R164, R165, R167, R168, R169, R170, R172, R173, R174, R175: 4.7k; 0603
R3, R5, R11, R16, R21, R26, R31, R36, R41, R46, R51, R56, R61, R66, R71, R76, R81, R86, R91, R96, R101, R106, R111, R116, R121, R126, R131, R136, R141, R146, R151, R156, R161, R166, R171: 1k; 0603
TRIG, TRIG1, TRIG2, TRIG3, TRIG4, TRIG5, TRIG6, TRIG7, TRIG8, TRIG9, TRIG10, TRIG11, TRIG12, TRIG13, TRIG14, TRIG15, TRIG16, TRIG17, TRIG18, TRIG19, TRIG20, TRIG21, TRIG22, TRIG23, TRIG24, TRIG25, TRIG26, TRIG27, TRIG28, TRIG29, TRIG30, TRIG31, TRIG32, TRIG33, TRIG34: JUMPER-SMT_2_NC_TRACE_SILK; SMT-JUMPER_2_NC_TRACE_SILK
U1, U2, U3, U4, U5, U6, U7, U8, U9, U10, U11, U12, U13, U14, U15, U16, U17, U18, U19, U20, U21, U22, U23, U24, U25, U26, U27, U28, U29, U30, U31, U32, U33, U34, U35: KX134; KX13X
U$1, U$28, U$52, U$61, U$85, U$94, U$118, U$127, U$151, U$160, U$184, U$193, U$217, U$226, U$250, U$259, U$283, U$292, U$316, U$325, U$349, U$358, U$382, U$391, U$415, U$424, U$448, U$457, U$481, U$490, U$514, U$523, U$547, U$556, U$580, U$589, U$613, U$622, U$646, U$655, U$679, U$688, U$712, U$721, U$745, U$754, U$778, U$787, U$811, U$820, U$844, U$853, U$877, U$886, U$910, U$919, U$943, U$952, U$976, U$985, U$1009, U$1018, U$1042, U$1051, U$1075, U$1084, U$1108, U$1117, U$1141, U$1150: X0
U$2, U$16, U$67, U$100, U$133, U$166, U$199, U$232, U$265, U$298, U$331, U$364, U$397, U$430, U$463, U$496, U$529, U$562, U$595, U$628, U$661, U$694, U$727, U$760, U$793, U$826, U$859, U$892, U$925, U$958, U$991, U$1024, U$1057, U$1090, U$1123: #SCL#0
U$3, U$35, U$68, U$101, U$134, U$167, U$200, U$233, U$266, U$299, U$332, U$365, U$398, U$431, U$464, U$497, U$530, U$563, U$596, U$629, U$662, U$695, U$728, U$761, U$794, U$827, U$860, U$893, U$926, U$959, U$992, U$1025, U$1058, U$1091, U$1124: #SDA#0
U$4, U$5, U$36, U$37, U$69, U$70, U$102, U$103, U$135, U$136, U$168, U$169, U$201, U$202, U$234, U$235, U$267, U$268, U$300, U$301, U$333, U$334, U$366, U$367, U$399, U$400, U$432, U$433, U$465, U$466, U$498, U$499, U$531, U$532, U$564, U$565, U$597, U$598, U$630, U$631, U$663, U$664, U$696, U$697, U$729, U$730, U$762, U$763, U$795, U$796, U$828, U$829, U$861, U$862, U$894, U$895, U$927, U$928, U$960, U$961, U$993, U$994, U$1026, U$1027, U$1059, U$1060, U$1092, U$1093, U$1125, U$1126: #3V3#0
U$6, U$7, U$38, U$39, U$71, U$72, U$104, U$105, U$137, U$138, U$170, U$171, U$203, U$204, U$236, U$237, U$269, U$270, U$302, U$303, U$335, U$336, U$368, U$369, U$401, U$402, U$434, U$435, U$467, U$468, U$500, U$501, U$533, U$534, U$566, U$567, U$599, U$600, U$632, U$633, U$665, U$666, U$698, U$699, U$731, U$732, U$764, U$765, U$797, U$798, U$830, U$831, U$863, U$864, U$896, U$897, U$929, U$930, U$962, U$963, U$995, U$996, U$1028, U$1029, U$1061, U$1062, U$1094, U$1095, U$1127, U$1128: #GND#0
U$8, U$9, U$40, U$41, U$73, U$74, U$106, U$107, U$139, U$140, U$172, U$173, U$205, U$206, U$238, U$239, U$271, U$272, U$304, U$305, U$337, U$338, U$370, U$371, U$403, U$404, U$436, U$437, U$469, U$470, U$502, U$503, U$535, U$536, U$568, U$569, U$601, U$602, U$634, U$635, U$667, U$668, U$700, U$701, U$733, U$734, U$766, U$767, U$799, U$800, U$832, U$833, U$865, U$866, U$898, U$899, U$931, U$932, U$964, U$965, U$997, U$998, U$1030, U$1031, U$1063, U$1064, U$1096, U$1097, U$1129, U$1130: ##CS##0
U$10, U$56, U$89, U$122, U$155, U$188, U$221, U$254, U$287, U$320, U$353, U$386, U$419, U$452, U$485, U$518, U$551, U$584, U$617, U$650, U$683, U$716, U$749, U$782, U$815, U$848, U$881, U$914, U$947, U$980, U$1013, U$1046, U$1079, U$1112, U$1145: #ADR#0
U$11, U$15, U$57, U$58, U$90, U$91, U$123, U$124, U$156, U$157, U$189, U$190, U$222, U$223, U$255, U$256, U$288, U$289, U$321, U$322, U$354, U$355, U$387, U$388, U$420, U$421, U$453, U$454, U$486, U$487, U$519, U$520, U$552, U$553, U$585, U$586, U$618, U$619, U$651, U$652, U$684, U$685, U$717, U$718, U$750, U$751, U$783, U$784, U$816, U$817, U$849, U$850, U$882, U$883, U$915, U$916, U$948, U$949, U$981, U$982, U$1014, U$1015, U$1047, U$1048, U$1080, U$1081, U$1113, U$1114, U$1146, U$1147: #TRIG#0
U$12, U$13, U$42, U$43, U$75, U$76, U$108, U$109, U$141, U$142, U$174, U$175, U$207, U$208, U$240, U$241, U$273, U$274, U$306, U$307, U$339, U$340, U$372, U$373, U$405, U$406, U$438, U$439, U$471, U$472, U$504, U$505, U$537, U$538, U$570, U$571, U$603, U$604, U$636, U$637, U$669, U$670, U$702, U$703, U$735, U$736, U$768, U$769, U$801, U$802, U$834, U$835, U$867, U$868, U$900, U$901, U$933, U$934, U$966, U$967, U$999, U$1000, U$1032, U$1033, U$1065, U$1066, U$1098, U$1099, U$1131, U$1132: #INT1#0
U$14, U$47, U$80, U$113, U$146, U$179, U$212, U$245, U$278, U$311, U$344, U$377, U$410, U$443, U$476, U$509, U$542, U$575, U$608, U$641, U$674, U$707, U$740, U$773, U$806, U$839, U$872, U$905, U$938, U$971, U$1004, U$1037, U$1070, U$1103, U$1136: 0X1E0
U$17, U$59, U$92, U$125, U$158, U$191, U$224, U$257, U$290, U$323, U$356, U$389, U$422, U$455, U$488, U$521, U$554, U$587, U$620, U$653, U$686, U$719, U$752, U$785, U$818, U$851, U$884, U$917, U$950, U$983, U$1016, U$1049, U$1082, U$1115, U$1148: #TRIG#2
U$18, U$19, U$44, U$45, U$77, U$78, U$110, U$111, U$143, U$144, U$176, U$177, U$209, U$210, U$242, U$243, U$275, U$276, U$308, U$309, U$341, U$342, U$374, U$375, U$407, U$408, U$440, U$441, U$473, U$474, U$506, U$507, U$539, U$540, U$572, U$573, U$605, U$606, U$638, U$639, U$671, U$672, U$704, U$705, U$737, U$738, U$770, U$771, U$803, U$804, U$836, U$837, U$869, U$870, U$902, U$903, U$935, U$936, U$968, U$969, U$1001, U$1002, U$1034, U$1035, U$1067, U$1068, U$1100, U$1101, U$1133, U$1134: #INT2#0
U$20, U$60, U$93, U$126, U$159, U$192, U$225, U$258, U$291, U$324, U$357, U$390, U$423, U$456, U$489, U$522, U$555, U$588, U$621, U$654, U$687, U$720, U$753, U$786, U$819, U$852, U$885, U$918, U$951, U$984, U$1017, U$1050, U$1083, U$1116, U$1149: #ADR#3
U$21, U$29, U$53, U$62, U$86, U$95, U$119, U$128, U$152, U$161, U$185, U$194, U$218, U$227, U$251, U$260, U$284, U$293, U$317, U$326, U$350, U$359, U$383, U$392, U$416, U$425, U$449, U$458, U$482, U$491, U$515, U$524, U$548, U$557, U$581, U$590, U$614, U$623, U$647, U$656, U$680, U$689, U$713, U$722, U$746, U$755, U$779, U$788, U$812, U$821, U$845, U$854, U$878, U$887, U$911, U$920, U$944, U$953, U$977, U$986, U$1010, U$1019, U$1043, U$1052, U$1076, U$1085, U$1109, U$1118, U$1142, U$1151: Y0
U$22, U$46, U$79, U$112, U$145, U$178, U$211, U$244, U$277, U$310, U$343, U$376, U$409, U$442, U$475, U$508, U$541, U$574, U$607, U$640, U$673, U$706, U$739, U$772, U$805, U$838, U$871, U$904, U$937, U$970, U$1003, U$1036, U$1069, U$1102, U$1135: #I2C#0
U$23, U$48, U$81, U$114, U$147, U$180, U$213, U$246, U$279, U$312, U$345, U$378, U$411, U$444, U$477, U$510, U$543, U$576, U$609, U$642, U$675, U$708, U$741, U$774, U$807, U$840, U$873, U$906, U$939, U$972, U$1005, U$1038, U$1071, U$1104, U$1137: 0X1F0
U$24, U$49, U$82, U$115, U$148, U$181, U$214, U$247, U$280, U$313, U$346, U$379, U$412, U$445, U$478, U$511, U$544, U$577, U$610, U$643, U$676, U$709, U$742, U$775, U$808, U$841, U$874, U$907, U$940, U$973, U$1006, U$1039, U$1072, U$1105, U$1138: #SDI#0
U$25, U$50, U$83, U$116, U$149, U$182, U$215, U$248, U$281, U$314, U$347, U$380, U$413, U$446, U$479, U$512, U$545, U$578, U$611, U$644, U$677, U$710, U$743, U$776, U$809, U$842, U$875, U$908, U$941, U$974, U$1007, U$1040, U$1073, U$1106, U$1139: #SCLK#0
U$26, U$51, U$84, U$117, U$150, U$183, U$216, U$249, U$282, U$315, U$348, U$381, U$414, U$447, U$480, U$513, U$546, U$579, U$612, U$645, U$678, U$711, U$744, U$777, U$810, U$843, U$876, U$909, U$942, U$975, U$1008, U$1041, U$1074, U$1107, U$1140: #SDO#0
U$27, U$66, U$99, U$132, U$165, U$198, U$231, U$264, U$297, U$330, U$363, U$396, U$429, U$462, U$495, U$528, U$561, U$594, U$627, U$660, U$693, U$726, U$759, U$792, U$825, U$858, U$891, U$924, U$957, U$990, U$1023, U$1056, U$1089, U$1122, U$1155: KX13X_ACCELEROMETER14
U$30, U$32, U$54, U$63, U$87, U$96, U$120, U$129, U$153, U$162, U$186, U$195, U$219, U$228, U$252, U$261, U$285, U$294, U$318, U$327, U$351, U$360, U$384, U$393, U$417, U$426, U$450, U$459, U$483, U$492, U$516, U$525, U$549, U$558, U$582, U$591, U$615, U$624, U$648, U$657, U$681, U$690, U$714, U$723, U$747, U$756, U$780, U$789, U$813, U$822, U$846, U$855, U$879, U$888, U$912, U$921, U$945, U$954, U$978, U$987, U$1011, U$1020, U$1044, U$1053, U$1077, U$1086, U$1110, U$1119, U$1143, U$1152: Z0
U$31, U$55, U$88, U$121, U$154, U$187, U$220, U$253, U$286, U$319, U$352, U$385, U$418, U$451, U$484, U$517, U$550, U$583, U$616, U$649, U$682, U$715, U$748, U$781, U$814, U$847, U$880, U$913, U$946, U$979, U$1012, U$1045, U$1078, U$1111, U$1144: PWR0
U$33, U$64, U$97, U$130, U$163, U$196, U$229, U$262, U$295, U$328, U$361, U$394, U$427, U$460, U$493, U$526, U$559, U$592, U$625, U$658, U$691, U$724, U$757, U$790, U$823, U$856, U$889, U$922, U$955, U$988, U$1021, U$1054, U$1087, U$1120, U$1153: 1320
U$34, U$65, U$98, U$131, U$164, U$197, U$230, U$263, U$296, U$329, U$362, U$395, U$428, U$461, U$494, U$527, U$560, U$593, U$626, U$659, U$692, U$725, U$758, U$791, U$824, U$857, U$890, U$923, U$956, U$989, U$1022, U$1055, U$1088, U$1121, U$1154: 1340

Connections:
3.3V: C1.1, C4.1, I2C.2, J2.2, J4.2, J5.2, PWR.2, R2.2, R4.2, U1.3, U1.7
3.3V1: C2.1, C3.1, I2C1.2, J3.2, J6.2, J8.2, PWR1.2, R9.2, R10.2, U2.3, U2.7
3.3V2: C5.1, C6.1, I2C2.2, J9.2, J10.2, J12.2, PWR2.2, R14.2, R15.2, U3.3, U3.7
3.3V3: C7.1, C8.1, I2C3.2, J13.2, J14.2, J16.2, PWR3.2, R19.2, R20.2, U4.3, U4.7
3.3V4: C9.1, C10.1, I2C4.2, J17.2, J18.2, J20.2, PWR4.2, R24.2, R25.2, U5.3, U5.7
3.3V5: C11.1, C12.1, I2C5.2, J21.2, J22.2, J24.2, PWR5.2, R29.2, R30.2, U6.3, U6.7
3.3V6: C13.1, C14.1, I2C6.2, J25.2, J26.2, J28.2, PWR6.2, R34.2, R35.2, U7.3, U7.7
3.3V7: C15.1, C16.1, I2C7.2, J29.2, J30.2, J32.2, PWR7.2, R39.2, R40.2, U8.3, U8.7
3.3V8: C17.1, C18.1, I2C8.2, J33.2, J34.2, J36.2, PWR8.2, R44.2, R45.2, U9.3, U9.7
3.3V9: C19.1, C20.1, I2C9.2, J37.2, J38.2, J40.2, PWR9.2, R49.2, R50.2, U10.3, U10.7
3.3V10: C21.1, C22.1, I2C10.2, J41.2, J42.2, J44.2, PWR10.2, R54.2, R55.2, U11.3, U11.7
3.3V11: C23.1, C24.1, I2C11.2, J45.2, J46.2, J48.2, PWR11.2, R59.2, R60.2, U12.3, U12.7
3.3V12: C25.1, C26.1, I2C12.2, J49.2, J50.2, J52.2, PWR12.2, R64.2, R65.2, U13.3, U13.7
3.3V13: C27.1, C28.1, I2C13.2, J53.2, J54.2, J56.2, PWR13.2, R69.2, R70.2, U14.3, U14.7
3.3V14: C29.1, C30.1, I2C14.2, J57.2, J58.2, J60.2, PWR14.2, R74.2, R75.2, U15.3, U15.7
3.3V15: C31.1, C32.1, I2C15.2, J61.2, J62.2, J64.2, PWR15.2, R79.2, R80.2, U16.3, U16.7
3.3V16: C33.1, C34.1, I2C16.2, J65.2, J66.2, J68.2, PWR16.2, R84.2, R85.2, U17.3, U17.7
3.3V17: C35.1, C36.1, I2C17.2, J69.2, J70.2, J72.2, PWR17.2, R89.2, R90.2, U18.3, U18.7
3.3V18: C37.1, C38.1, I2C18.2, J73.2, J74.2, J76.2, PWR18.2, R94.2, R95.2, U19.3, U19.7
3.3V19: C39.1, C40.1, I2C19.2, J77.2, J78.2, J80.2, PWR19.2, R99.2, R100.2, U20.3, U20.7
3.3V20: C41.1, C42.1, I2C20.2, J81.2, J82.2, J84.2, PWR20.2, R104.2, R105.2, U21.3, U21.7
3.3V21: C43.1, C44.1, I2C21.2, J85.2, J86.2, J88.2, PWR21.2, R109.2, R110.2, U22.3, U22.7
3.3V22: C45.1, C46.1, I2C22.2, J89.2, J90.2, J92.2, PWR22.2, R114.2, R115.2, U23.3, U23.7
3.3V23: C47.1, C48.1, I2C23.2, J93.2, J94.2, J96.2, PWR23.2, R119.2, R120.2, U24.3, U24.7
3.3V24: C49.1, C50.1, I2C24.2, J97.2, J98.2, J100.2, PWR24.2, R124.2, R125.2, U25.3, U25.7
3.3V25: C51.1, C52.1, I2C25.2, J101.2, J102.2, J104.2, PWR25.2, R129.2, R130.2, U26.3, U26.7
3.3V26: C53.1, C54.1, I2C26.2, J105.2, J106.2, J108.2, PWR26.2, R134.2, R135.2, U27.3, U27.7
3.3V27: C55.1, C56.1, I2C27.2, J109.2, J110.2, J112.2, PWR27.2, R139.2, R140.2, U28.3, U28.7
3.3V28: C57.1, C58.1, I2C28.2, J113.2, J114.2, J116.2, PWR28.2, R144.2, R145.2, U29.3, U29.7
3.3V29: C59.1, C60.1, I2C29.2, J117.2, J118.2, J120.2, PWR29.2, R149.2, R150.2, U30.3, U30.7
3.3V30: C61.1, C62.1, I2C30.2, J121.2, J122.2, J124.2, PWR30.2, R154.2, R155.2, U31.3, U31.7
3.3V31: C63.1, C64.1, I2C31.2, J125.2, J126.2, J128.2, PWR31.2, R159.2, R160.2, U32.3, U32.7
3.3V32: C65.1, C66.1, I2C32.2, J129.2, J130.2, J132.2, PWR32.2, R164.2, R165.2, U33.3, U33.7
3.3V33: C67.1, C68.1, I2C33.2, J133.2, J134.2, J136.2, PWR33.2, R169.2, R170.2, U34.3, U34.7
3.3V34: C69.1, C70.1, I2C34.2, J137.2, J138.2, J140.2, PWR34.2, R174.2, R175.2, U35.3, U35.7
!CS: J5.6, R2.1, U1.10
!CS1: J8.6, R9.1, U2.10
!CS2: J12.6, R14.1, U3.10
!CS3: J16.6, R19.1, U4.10
!CS4: J20.6, R24.1, U5.10
!CS5: J24.6, R29.1, U6.10
!CS6: J28.6, R34.1, U7.10
!CS7: J32.6, R39.1, U8.10
!CS8: J36.6, R44.1, U9.10
!CS9: J40.6, R49.1, U10.10
!CS10: J44.6, R54.1, U11.10
!CS11: J48.6, R59.1, U12.10
!CS12: J52.6, R64.1, U13.10
!CS13: J56.6, R69.1, U14.10
!CS14: J60.6, R74.1, U15.10
!CS15: J64.6, R79.1, U16.10
!CS16: J68.6, R84.1, U17.10
!CS17: J72.6, R89.1, U18.10
!CS18: J76.6, R94.1, U19.10
!CS19: J80.6, R99.1, U20.10
!CS20: J84.6, R104.1, U21.10
!CS21: J88.6, R109.1, U22.10
!CS22: J92.6, R114.1, U23.10
!CS23: J96.6, R119.1, U24.10
!CS24: J100.6, R124.1, U25.10
!CS25: J104.6, R129.1, U26.10
!CS26: J108.6, R134.1, U27.10
!CS27: J112.6, R139.1, U28.10
!CS28: J116.6, R144.1, U29.10
!CS29: J120.6, R149.1, U30.10
!CS30: J124.6, R154.1, U31.10
!CS31: J128.6, R159.1, U32.10
!CS32: J132.6, R164.1, U33.10
!CS33: J136.6, R169.1, U34.10
!CS34: J140.6, R174.1, U35.10
ADR/SDO: ADR.2, J5.5, U1.1
ADR/SDO1: ADR1.2, J8.5, U2.1
ADR/SDO2: ADR2.2, J12.5, U3.1
ADR/SDO3: ADR3.2, J16.5, U4.1
ADR/SDO4: ADR4.2, J20.5, U5.1
ADR/SDO5: ADR5.2, J24.5, U6.1
ADR/SDO6: ADR6.2, J28.5, U7.1
ADR/SDO7: ADR7.2, J32.5, U8.1
ADR/SDO8: ADR8.2, J36.5, U9.1
ADR/SDO9: ADR9.2, J40.5, U10.1
ADR/SDO10: ADR10.2, J44.5, U11.1
ADR/SDO11: ADR11.2, J48.5, U12.1
ADR/SDO12: ADR12.2, J52.5, U13.1
ADR/SDO13: ADR13.2, J56.5, U14.1
ADR/SDO14: ADR14.2, J60.5, U15.1
ADR/SDO15: ADR15.2, J64.5, U16.1
ADR/SDO16: ADR16.2, J68.5, U17.1
ADR/SDO17: ADR17.2, J72.5, U18.1
ADR/SDO18: ADR18.2, J76.5, U19.1
ADR/SDO19: ADR19.2, J80.5, U20.1
ADR/SDO20: ADR20.2, J84.5, U21.1
ADR/SDO21: ADR21.2, J88.5, U22.1
ADR/SDO22: ADR22.2, J92.5, U23.1
ADR/SDO23: ADR23.2, J96.5, U24.1
ADR/SDO24: ADR24.2, J100.5, U25.1
ADR/SDO25: ADR25.2, J104.5, U26.1
ADR/SDO26: ADR26.2, J108.5, U27.1
ADR/SDO27: ADR27.2, J112.5, U28.1
ADR/SDO28: ADR28.2, J116.5, U29.1
ADR/SDO29: ADR29.2, J120.5, U30.1
ADR/SDO30: ADR30.2, J124.5, U31.1
ADR/SDO31: ADR31.2, J128.5, U32.1
ADR/SDO32: ADR32.2, J132.5, U33.1
ADR/SDO33: ADR33.2, J136.5, U34.1
ADR/SDO34: ADR34.2, J140.5, U35.1
GND: ADR.1, C1.2, C4.2, D1.C, J2.1, J4.1, J5.1, TRIG.2, U1.8, U1.9
GND1: ADR1.1, C2.2, C3.2, D2.C, J3.1, J6.1, J8.1, TRIG1.2, U2.8, U2.9
GND2: ADR2.1, C5.2, C6.2, D3.C, J9.1, J10.1, J12.1, TRIG2.2, U3.8, U3.9
GND3: ADR3.1, C7.2, C8.2, D4.C, J13.1, J14.1, J16.1, TRIG3.2, U4.8, U4.9
GND4: ADR4.1, C9.2, C10.2, D5.C, J17.1, J18.1, J20.1, TRIG4.2, U5.8, U5.9
GND5: ADR5.1, C11.2, C12.2, D6.C, J21.1, J22.1, J24.1, TRIG5.2, U6.8, U6.9
GND6: ADR6.1, C13.2, C14.2, D7.C, J25.1, J26.1, J28.1, TRIG6.2, U7.8, U7.9
GND7: ADR7.1, C15.2, C16.2, D8.C, J29.1, J30.1, J32.1, TRIG7.2, U8.8, U8.9
GND8: ADR8.1, C17.2, C18.2, D9.C, J33.1, J34.1, J36.1, TRIG8.2, U9.8, U9.9
GND9: ADR9.1, C19.2, C20.2, D10.C, J37.1, J38.1, J40.1, TRIG9.2, U10.8, U10.9
GND10: ADR10.1, C21.2, C22.2, D11.C, J41.1, J42.1, J44.1, TRIG10.2, U11.8, U11.9
GND11: ADR11.1, C23.2, C24.2, D12.C, J45.1, J46.1, J48.1, TRIG11.2, U12.8, U12.9
GND12: ADR12.1, C25.2, C26.2, D13.C, J49.1, J50.1, J52.1, TRIG12.2, U13.8, U13.9
GND13: ADR13.1, C27.2, C28.2, D14.C, J53.1, J54.1, J56.1, TRIG13.2, U14.8, U14.9
GND14: ADR14.1, C29.2, C30.2, D15.C, J57.1, J58.1, J60.1, TRIG14.2, U15.8, U15.9
GND15: ADR15.1, C31.2, C32.2, D16.C, J61.1, J62.1, J64.1, TRIG15.2, U16.8, U16.9
GND16: ADR16.1, C33.2, C34.2, D17.C, J65.1, J66.1, J68.1, TRIG16.2, U17.8, U17.9
GND17: ADR17.1, C35.2, C36.2, D18.C, J69.1, J70.1, J72.1, TRIG17.2, U18.8, U18.9
GND18: ADR18.1, C37.2, C38.2, D19.C, J73.1, J74.1, J76.1, TRIG18.2, U19.8, U19.9
GND19: ADR19.1, C39.2, C40.2, D20.C, J77.1, J78.1, J80.1, TRIG19.2, U20.8, U20.9
GND20: ADR20.1, C41.2, C42.2, D21.C, J81.1, J82.1, J84.1, TRIG20.2, U21.8, U21.9
GND21: ADR21.1, C43.2, C44.2, D22.C, J85.1, J86.1, J88.1, TRIG21.2, U22.8, U22.9
GND22: ADR22.1, C45.2, C46.2, D23.C, J89.1, J90.1, J92.1, TRIG22.2, U23.8, U23.9
GND23: ADR23.1, C47.2, C48.2, D24.C, J93.1, J94.1, J96.1, TRIG23.2, U24.8, U24.9
GND24: ADR24.1, C49.2, C50.2, D25.C, J97.1, J98.1, J100.1, TRIG24.2, U25.8, U25.9
GND25: ADR25.1, C51.2, C52.2, D26.C, J101.1, J102.1, J104.1, TRIG25.2, U26.8, U26.9
GND26: ADR26.1, C53.2, C54.2, D27.C, J105.1, J106.1, J108.1, TRIG26.2, U27.8, U27.9
GND27: ADR27.1, C55.2, C56.2, D28.C, J109.1, J110.1, J112.1, TRIG27.2, U28.8, U28.9
GND28: ADR28.1, C57.2, C58.2, D29.C, J113.1, J114.1, J116.1, TRIG28.2, U29.8, U29.9
GND29: ADR29.1, C59.2, C60.2, D30.C, J117.1, J118.1, J120.1, TRIG29.2, U30.8, U30.9
GND30: ADR30.1, C61.2, C62.2, D31.C, J121.1, J122.1, J124.1, TRIG30.2, U31.8, U31.9
GND31: ADR31.1, C63.2, C64.2, D32.C, J125.1, J126.1, J128.1, TRIG31.2, U32.8, U32.9
GND32: ADR32.1, C65.2, C66.2, D33.C, J129.1, J130.1, J132.1, TRIG32.2, U33.8, U33.9
GND33: ADR33.1, C67.2, C68.2, D34.C, J133.1, J134.1, J136.1, TRIG33.2, U34.8, U34.9
GND34: ADR34.1, C69.2, C70.2, D35.C, J137.1, J138.1, J140.1, TRIG34.2, U35.8, U35.9
INT1: J1.2, U1.5
INT2: J1.3, U1.6
INT3: J7.2, U2.5
INT4: J7.3, U2.6
INT5: J11.2, U3.5
INT6: J11.3, U3.6
INT7: J15.2, U4.5
INT8: J15.3, U4.6
INT9: J19.2, U5.5
INT10: J19.3, U5.6
INT11: J23.2, U6.5
INT12: J23.3, U6.6
INT13: J27.2, U7.5
INT14: J27.3, U7.6
INT15: J31.2, U8.5
INT16: J31.3, U8.6
INT17: J35.2, U9.5
INT18: J35.3, U9.6
INT19: J39.2, U10.5
INT20: J39.3, U10.6
INT21: J43.2, U11.5
INT22: J43.3, U11.6
INT23: J47.2, U12.5
INT24: J47.3, U12.6
INT25: J51.2, U13.5
INT26: J51.3, U13.6
INT27: J55.2, U14.5
INT28: J55.3, U14.6
INT29: J59.2, U15.5
INT30: J59.3, U15.6
INT31: J63.2, U16.5
INT32: J63.3, U16.6
INT33: J67.2, U17.5
INT34: J67.3, U17.6
INT35: J71.2, U18.5
INT36: J71.3, U18.6
INT37: J75.2, U19.5
INT38: J75.3, U19.6
INT39: J79.2, U20.5
INT40: J79.3, U20.6
INT41: J83.2, U21.5
INT42: J83.3, U21.6
INT43: J87.2, U22.5
INT44: J87.3, U22.6
INT45: J91.2, U23.5
INT46: J91.3, U23.6
INT47: J95.2, U24.5
INT48: J95.3, U24.6
INT49: J99.2, U25.5
INT50: J99.3, U25.6
INT51: J103.2, U26.5
INT52: J103.3, U26.6
INT53: J107.2, U27.5
INT54: J107.3, U27.6
INT55: J111.2, U28.5
INT56: J111.3, U28.6
INT57: J115.2, U29.5
INT58: J115.3, U29.6
INT59: J119.2, U30.5
INT60: J119.3, U30.6
INT61: J123.2, U31.5
INT62: J123.3, U31.6
INT63: J127.2, U32.5
INT64: J127.3, U32.6
INT65: J131.2, U33.5
INT66: J131.3, U33.6
INT67: J135.2, U34.5
INT68: J135.3, U34.6
INT69: J139.2, U35.5
INT70: J139.3, U35.6
unnamed: PWR.1, R3.2
unnamed: I2C.3, R1.2
unnamed: D1.A, R3.1
unnamed: I2C.1, R7.2
unnamed: ADR.3, R4.1
unnamed: D2.A, R5.1
unnamed: PWR1.1, R5.2
unnamed: I2C1.3, R6.2
unnamed: I2C1.1, R8.2
unnamed: ADR1.3, R10.1
unnamed: D3.A, R11.1
unnamed: PWR2.1, R11.2
unnamed: I2C2.3, R12.2
unnamed: I2C2.1, R13.2
unnamed: ADR2.3, R15.1
unnamed: D4.A, R16.1
unnamed: PWR3.1, R16.2
unnamed: I2C3.3, R17.2
unnamed: I2C3.1, R18.2
unnamed: ADR3.3, R20.1
unnamed: D5.A, R21.1
unnamed: PWR4.1, R21.2
unnamed: I2C4.3, R22.2
unnamed: I2C4.1, R23.2
unnamed: ADR4.3, R25.1
unnamed: D6.A, R26.1
unnamed: PWR5.1, R26.2
unnamed: I2C5.3, R27.2
unnamed: I2C5.1, R28.2
unnamed: ADR5.3, R30.1
unnamed: D7.A, R31.1
unnamed: PWR6.1, R31.2
unnamed: I2C6.3, R32.2
unnamed: I2C6.1, R33.2
unnamed: ADR6.3, R35.1
unnamed: D8.A, R36.1
unnamed: PWR7.1, R36.2
unnamed: I2C7.3, R37.2
unnamed: I2C7.1, R38.2
unnamed: ADR7.3, R40.1
unnamed: D9.A, R41.1
unnamed: PWR8.1, R41.2
unnamed: I2C8.3, R42.2
unnamed: I2C8.1, R43.2
unnamed: ADR8.3, R45.1
unnamed: D10.A, R46.1
unnamed: PWR9.1, R46.2
unnamed: I2C9.3, R47.2
unnamed: I2C9.1, R48.2
unnamed: ADR9.3, R50.1
unnamed: D11.A, R51.1
unnamed: PWR10.1, R51.2
unnamed: I2C10.3, R52.2
unnamed: I2C10.1, R53.2
unnamed: ADR10.3, R55.1
unnamed: D12.A, R56.1
unnamed: PWR11.1, R56.2
unnamed: I2C11.3, R57.2
unnamed: I2C11.1, R58.2
unnamed: ADR11.3, R60.1
unnamed: D13.A, R61.1
unnamed: PWR12.1, R61.2
unnamed: I2C12.3, R62.2
unnamed: I2C12.1, R63.2
unnamed: ADR12.3, R65.1
unnamed: D14.A, R66.1
unnamed: PWR13.1, R66.2
unnamed: I2C13.3, R67.2
unnamed: I2C13.1, R68.2
unnamed: ADR13.3, R70.1
unnamed: D15.A, R71.1
unnamed: PWR14.1, R71.2
unnamed: I2C14.3, R72.2
unnamed: I2C14.1, R73.2
unnamed: ADR14.3, R75.1
unnamed: D16.A, R76.1
unnamed: PWR15.1, R76.2
unnamed: I2C15.3, R77.2
unnamed: I2C15.1, R78.2
unnamed: ADR15.3, R80.1
unnamed: D17.A, R81.1
unnamed: PWR16.1, R81.2
unnamed: I2C16.3, R82.2
unnamed: I2C16.1, R83.2
unnamed: ADR16.3, R85.1
unnamed: D18.A, R86.1
unnamed: PWR17.1, R86.2
unnamed: I2C17.3, R87.2
unnamed: I2C17.1, R88.2
unnamed: ADR17.3, R90.1
unnamed: D19.A, R91.1
unnamed: PWR18.1, R91.2
unnamed: I2C18.3, R92.2
unnamed: I2C18.1, R93.2
unnamed: ADR18.3, R95.1
unnamed: D20.A, R96.1
unnamed: PWR19.1, R96.2
unnamed: I2C19.3, R97.2
unnamed: I2C19.1, R98.2
unnamed: ADR19.3, R100.1
unnamed: D21.A, R101.1
unnamed: PWR20.1, R101.2
unnamed: I2C20.3, R102.2
unnamed: I2C20.1, R103.2
unnamed: ADR20.3, R105.1
unnamed: D22.A, R106.1
unnamed: PWR21.1, R106.2
unnamed: I2C21.3, R107.2
unnamed: I2C21.1, R108.2
unnamed: ADR21.3, R110.1
unnamed: D23.A, R111.1
unnamed: PWR22.1, R111.2
unnamed: I2C22.3, R112.2
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

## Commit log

2020-11-09 adding axes
    [Qwiic_KX134.brd]
2020-11-11 Post review/checklist changes
    [Qwiic_KX134.brd, Qwiic_KX134.sch]
2021-01-14 adding 132/134 checkboxes
    [Qwiic_KX134.GBL, Qwiic_KX134.GBO, Qwiic_KX134.GBP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]
2021-01-18 updating version number and orientation for review
    [Qwiic_KX134.brd, Qwiic_KX134.sch]
2021-01-19 post design review, computer transfer
    [Qwiic_KX134.brd, Qwiic_KX134.sch]
2021-01-20 post checklist changes
    [Qwiic_KX134.brd, Qwiic_KX134.sch]
2021-01-21 adding panels
    [Qwiic_KX134.GBL, Qwiic_KX134.GBO, Qwiic_KX134.GBS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]
2021-03-24 Repanelizes design after fixing silk
    * There is a single PCB but there are jumpers with paste to indicate version. The paste layers have been placed into their own files with the production folder so that production can order the correct foils.
    [Qwiic_KX132 (SEN-17871) Panel.GTP, Qwiic_KX134 (SEN-17589) Panel.GTP, Qwiic_KX13X-Panel.GBL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]
2026-03-17 added hardware assembly

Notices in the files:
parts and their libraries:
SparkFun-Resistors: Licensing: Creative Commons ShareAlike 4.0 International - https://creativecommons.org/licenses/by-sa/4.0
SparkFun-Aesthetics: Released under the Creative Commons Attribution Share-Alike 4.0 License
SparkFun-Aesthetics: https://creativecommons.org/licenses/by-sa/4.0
